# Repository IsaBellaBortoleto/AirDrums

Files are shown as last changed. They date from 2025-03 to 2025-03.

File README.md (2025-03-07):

## <h1 align="center">AIRDRUMS</h1>
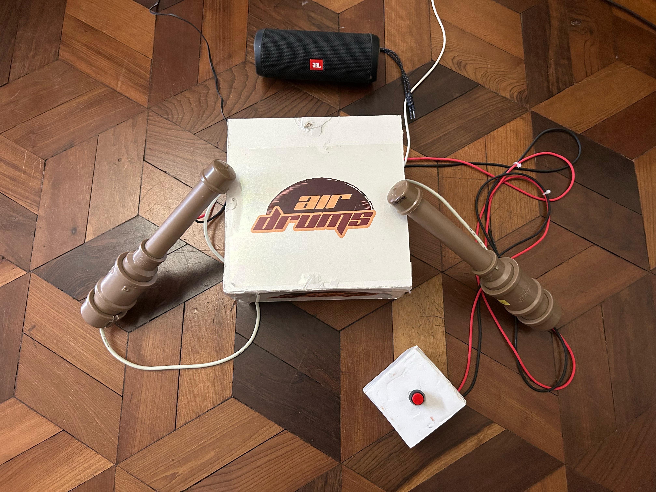
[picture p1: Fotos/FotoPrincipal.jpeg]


Como projeto da disciplina de Oficina de Integração I foi realizado o AirDrums, um sistema que utiliza sensores de movimento e tecnologia digital para simular a experiência de tocar bateria sem a necessidade de um instrumento físico volumoso.
A proposta do trabalho é oferecer uma alternativa compacta, permitindo a prática sem restrições de espaço ou ruído.

## Desenvolvedores  

- Bruna Medeiros Teixeira  
- Isabela Bella Bortoleto  
- Guilherme de Souza Carneiro Garcia  

## ⚙️ Componentes Utilizados  

- **ESP32 Dev Kit V1**: Microcontrolador principal do projeto, responsável por processar os dados dos sensores, interpretar os movimentos e gerenciar a reprodução dos sons da bateria virtual. Nesse contexto, dois ESP32 são usados para capturar os dados das baquetas e um ESP32 que processa os sinais e executa o áudio. A partir de agora, ele será chamado de ESP32 central.  

- **IMU MPU6050 (Inertial Measurement Unit - Unidade de Medição Inercial)**: Unidade de acelerômetro e giroscópio integrado às baquetas, detecta os movimentos do usuário, identificando a posição das batidas na bateria virtual.  

- **DAC UDA1334A (Digital-to-Analog Converter - Conversor Digital-para-Analógico)**: Converte os sinais digitais de áudio do ESP32 central em sinais analógicos, permitindo a reprodução dos sons da bateria através de alto-falantes ou fones de ouvido.  

- **MicroSD**: Armazena os arquivos de áudio das peças da bateria (tons, pratos e bumbo) e fornece os dados para reprodução conforme os comandos recebidos.  

- **Botão Push-Button**: Botão de ativação, aciona manualmente o som do bumbo, simulando o pedal tradicional da bateria.  

- **Fonte de Alimentação para protoboard 3,3/5 V**: Responsável por fornecer energia para todos os módulos eletrônicos do sistema.  

Além deles, foram utilizadas placas universais (PCBs) para a integração elétrica das baquetas e do ESP32 central, uma estrutura de madeira projetada para acomodar os componentes e garantir sua segurança, cabos Manga para comunicação e alimentação das baquetas virtuais e uma estrutura de tubos de PVC para proteger e realizar o acabamento das baquetas, um resistor de 10kΩ para limitar a corrente no circuito do botão e massa para madeira para aperfeiçoar o acabamento da estrutura externa. Também foram utilizados jumpers para conectar os diversos módulos do circuito.

## 🔨 Desenvolvimento  

Os tópicos do desenvolvimento seguirão o fluxo de informações enviadas pelos componentes da bateria: ao serem acionadas, as baquetas ou o bumbo enviam os dados para o ESP32 central, que então processa e reproduz o som correspondente.  

A **Figura 2** apresenta uma representação geral do projeto.  

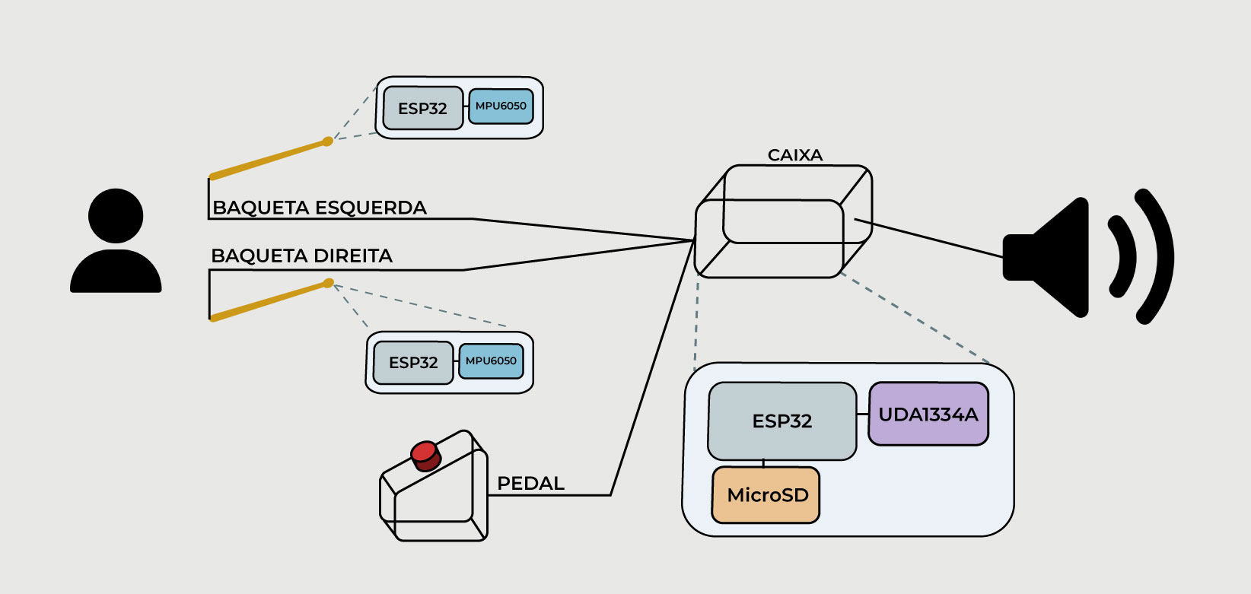
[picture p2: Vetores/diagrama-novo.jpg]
>  <br/>
> Figura 2: Diagrama funcional das AirDrums, Fonte: Autoria Própria.

### 🎯 Funcionamento das Baquetas  

O funcionamento das baquetas é baseado na integração de um **ESP32** e um **módulo MPU-6050** em cada baqueta, como mostra a **Figura 2**. Ao ligar o aparelho, o módulo realiza uma calibração inicial e começa a captar os giros de dois eixos principais:  

- O giro no eixo **Y** é usado para captar os movimentos de batida.  
- O giro no eixo **Z** é utilizado para determinar a região das partes da bateria.  

No código das baquetas, foi utilizada a biblioteca do módulo desenvolvida **Electronic Cats (Cats, 2025)**, que possibilita a ativação do **Digital Motion Processor (DMP)**.  

O **DMP** é um circuito integrado ao **MPU-6050**, que tem como objetivo refinar a carga do processamento das informações fornecidas pelo módulo, realizando cálculos complexos e aplicando filtros nos dados brutos captados pelo sensor. Esse processamento é realizado por um código proprietário, desenvolvido pela fabricante do módulo, a **InvenSense**, de código fechado.  

Como resultado, ele entrega informações mais elaboradas, na forma dos ângulos **Yaw** (Guinada, rotação no eixo Z), **Pitch** (Arfagem, rotação no eixo X) e **Roll** (Rolamento, rotação no eixo Y), como são chamados após a aplicação dos filtros internos, processados diretamente pelo DMP.  

Com isso, definimos zonas de ativação para cada parte da bateria através das baquetas, utilizando a posição relativa ao eixo **Z (Yaw)**. A **Figura 3** descreve os pontos de ativação de cada componente da bateria, assim como os ângulos de ativação.  

As zonas foram assim determinadas para respeitar as partes naturais da bateria, garantir precisão e fácil utilização do aparelho, sendo que as **faixas neutras** não correspondem a nenhum som e foram definidas para evitar conflito entre os pratos e tons.  

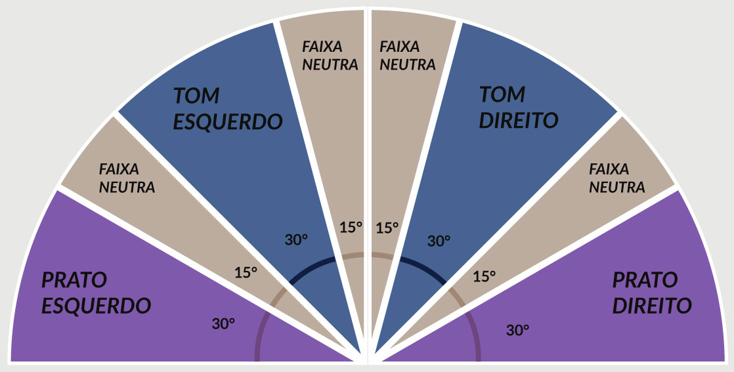
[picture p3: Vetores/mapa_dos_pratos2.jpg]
>  <br/>
> Figura 3: Ângulos de Ativação das Partes da Bateria, Fonte: Autoria Própria.<br />

Para o lançamento do som, utilizamos a posição relativa ao eixo **Y (Roll)**, é utilizado um ângulo de 10° para ativação, uma vez que corresponde ao movimento natural de tocar a bateria.  
O **ESP32** trabalha de forma sequencial para identificar a ativação da peça, o módulo envia essa informação para a parte central. Toda a comunicação dos módulos **MPU** é feita através do protocolo **I2C**, que manda os dados pós-processados para as **ESP32** da baqueta, então esses identificam a parte da bateria e enviam essa informação em formato de texto através da porta de comunicação **TX** utilizando o protocolo de comunicação **UART** (**Universal Asynchronous Receiver-Transmitter**), utilizado na troca de informações entre o microcontrolador da baqueta e o central, responsável por processar e reproduzir o som correto.  

Essa informação é transmitida por meio de um cabo **Manga** de três vias, que, além de transmitir os dados, também fornece alimentação de 5 V para todo o sistema.  

Por fim, as baquetas foram montadas em uma estrutura de **PVC**, projetada para se assemelhar ao instrumento original e proporcionar maior ergonomia durante o uso. A estrutura é composta por dois tubos de **PVC**, um com diâmetro de 40 mm e outro de 20 mm, conectados por luvas de redução por meio de encaixe por pressão. Para acabamento e proteção das extremidades, foram utilizadas tampas apropriadas para cada diâmetro. As baquetas possuem um comprimento de 28,5 cm no total.  

### 🔊 Implementação do som  
Após as baquetas detectarem a parte correspondente da bateria, essas informações são enviadas para o **ESP32** central, responsável pelo processamento dos dados e reprodução do som. Nele, temos três módulos integrados ao projeto:

- **Módulo Micro-SD**: O sistema utiliza um cartão microSD para armazenar os arquivos de áudio das diferentes peças do instrumento. O microprocessador central acessa esses arquivos, que estão em formato digital, através da biblioteca **SD.h**. Para otimizar a reprodução, os dados dos arquivos são lidos sequencialmente e armazenados temporariamente em um buffer na memória do **ESP32**, antes de serem processados e enviados para os alto-falantes.
  
- **Botão de Ativação do Bumbo**: O **ESP32** central controla a ativação do bumbo por meio de um botão (**push button**), a detecção do acionamento ocorre através da variação da diferença de potencial (**DDP**) no pino digital do **ESP32** ao qual o botão está conectado. Quando pressionado, o botão fecha o circuito, alterando o nível lógico do pino de entrada, permitindo que o **ESP32** identifique a ativação do comando. O botão está conectado eletricamente à placa de circuito impresso (**PCB**) central por meio de um fio soldado de 2,0 m de comprimento. Para facilitar o acionamento com o pé, o botão foi integrado a uma estrutura de madeira com uma tampa angulada, projetada para dar mais conforto e ergonomia durante o uso. A **Figura 6** demonstra o modelo 3D projetado para a caixa do bumbo, feito no **SolidWorks**.  

As dimensões do bumbo são:  
- Parte superior: quadrado de 8,0 cm x 8,0 cm;  
- Frente: retângulo de 7,1 cm x 8,1 cm;  
- Laterais trapezoidais: base inferior de 8 cm, base superior inclinada de 8,5 cm, altura variando entre 7,0 cm e 9,0 cm;  
- Parte traseira: retângulo de 10,3 cm x 8,1 cm;  
- Fundo: retângulo de 8,2 cm x 8,0 cm.  

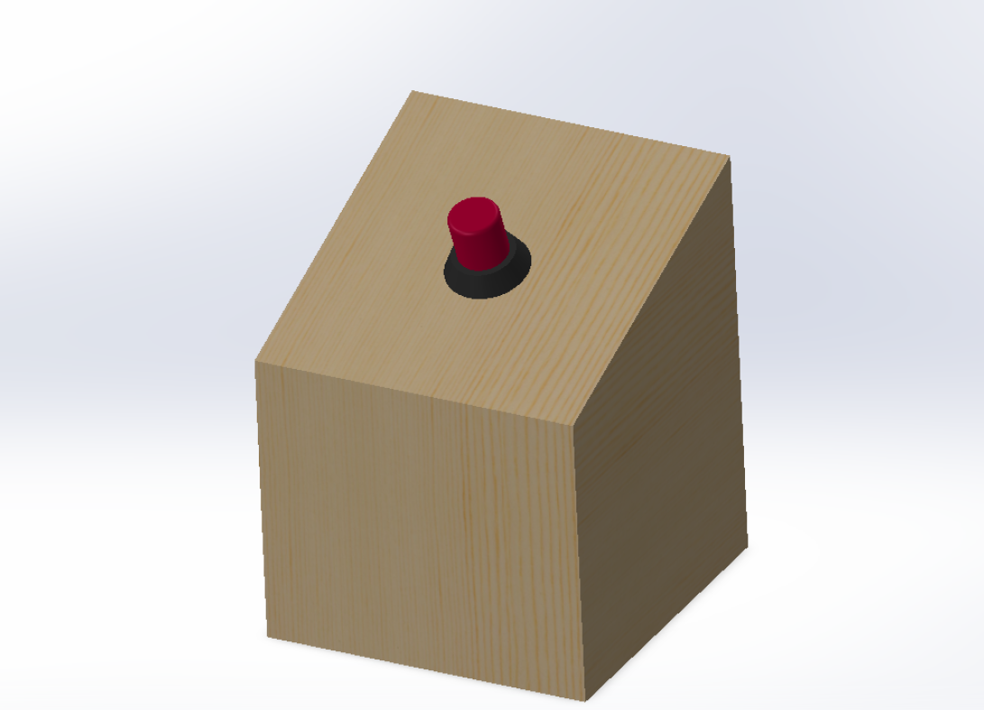
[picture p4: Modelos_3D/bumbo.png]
>  <br/>
> Figura 4. Modelo 3D da Estrutura do Bumbo. Fonte: Autoria Própria.

- **Módulo DAC UDA1334**: Após a abertura dos arquivos de áudio no módulo microSD e o acionamento de uma peça da bateria por meio das baquetas ou o toque no botão que integra o bumbo, inicia-se o processo de reprodução do som. O ESP32 utiliza a interface I2S, um protocolo otimizado para transmissão de áudio digital com baixa latência. A biblioteca I2S.h permite maior flexibilidade e ajustes na configuração do áudio com o DAC UDA1334. Para o projeto, escolhemos um padrão de áudio amplamente utilizado, com taxa de amostragem de 44,1 kHz e 16 bits. Além disso, foi utilizado o formato WAV, um formato de áudio não compactado que armazena os dados no padrão PCM (Pulse Code Modulation).

O UDA1334 recebe esses dados digitais enviados pelo ESP32 e os converte em sinais analógicos, que são representações contínuas das ondas sonoras. Diferente do áudio digital, que processa o som em valores discretos (bits), o sinal analógico corresponde às oscilações da pressão do ar, tornando o som audível para o ser humano. Como alto-falantes e fones de ouvido operam exclusivamente com sinais analógicos, eles convertem essas variações elétricas em ondas sonoras e reproduzem o áudio para esses dispositivos através de uma saída P2.

Por fim, todo esse sistema foi soldado em uma PCB central de 10 por 10 cm, junto com um módulo regulador de tensão de 5 V para protoboard e um cabo de alimentação de 9 V, responsável por fornecer energia ao sistema. Tudo isso foi colocado em uma estrutura quadrada de madeira, com dimensões de 20,2 x 20,2 x 14 cm.

O esquema elétrico, desenvolvido por meio do software EasyEDA, pode ser visualizado na Figura 5.

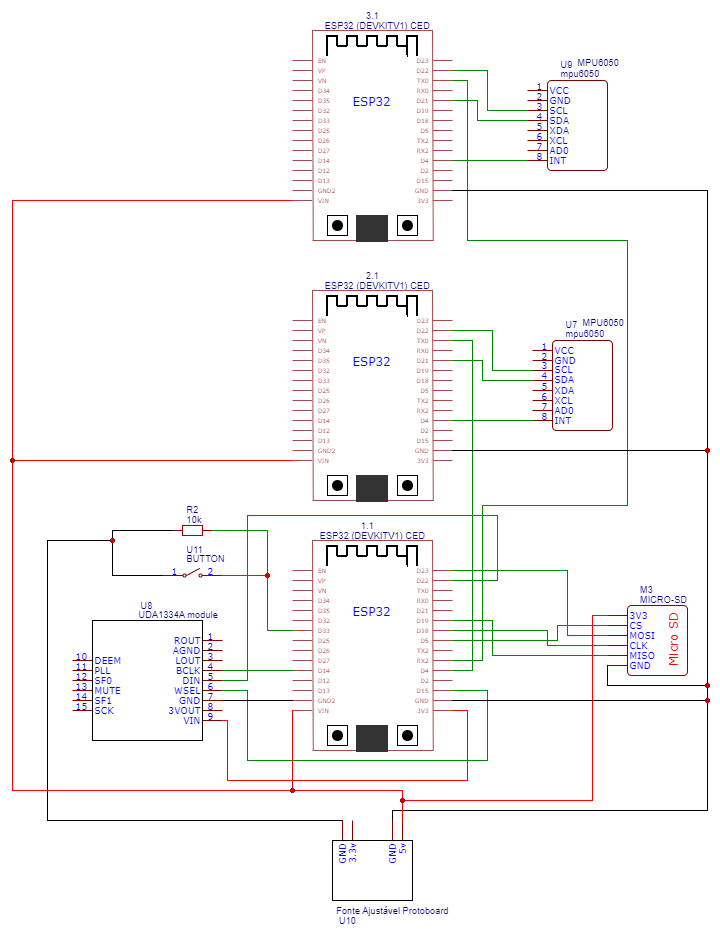
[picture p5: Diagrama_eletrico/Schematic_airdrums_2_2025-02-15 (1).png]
>  <br/>
> Figura 5. Diagrama do Circuito Elétrico. Fonte: Autoria Própria.

---

Para mais informações, leia o [artigo disponível no repositório.](https://github.com/IsaBellaBortoleto/AirDrums/blob/main/Artigo.pdf)

<p float="left">
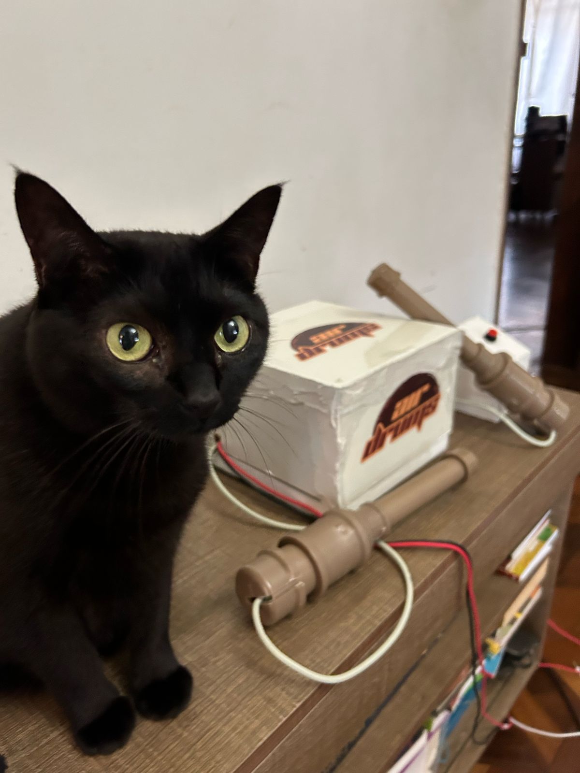
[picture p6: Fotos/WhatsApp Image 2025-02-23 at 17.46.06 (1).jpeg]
  
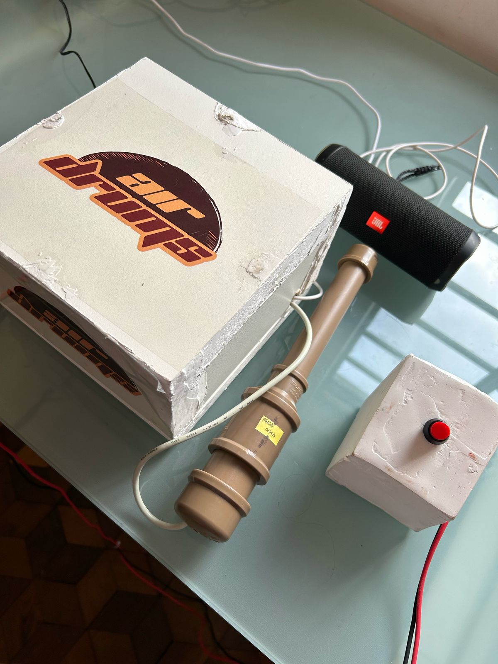
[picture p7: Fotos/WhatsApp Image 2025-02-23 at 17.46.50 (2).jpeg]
   
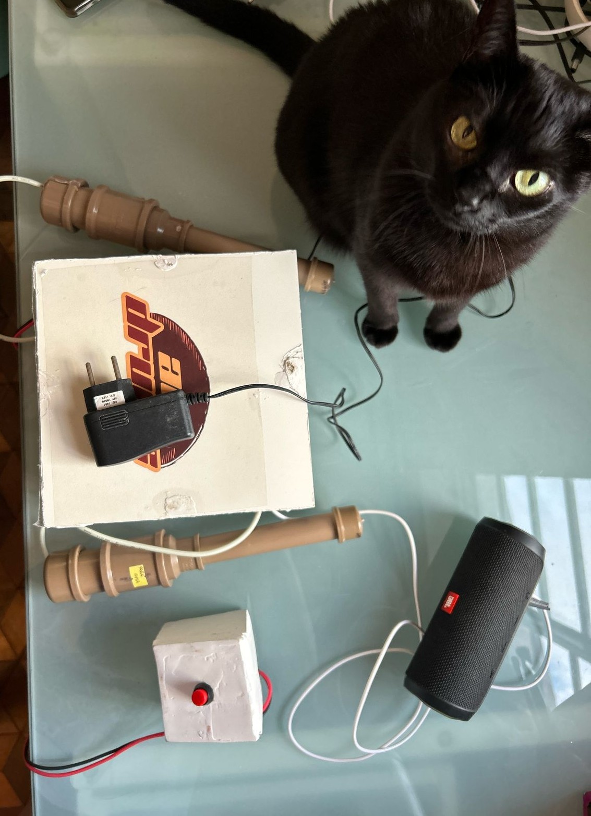
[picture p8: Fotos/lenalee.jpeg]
  
</p>

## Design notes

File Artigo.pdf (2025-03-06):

## Projeto AirDrums

Guilherme de S.C Garcia ∗ Bruna M Teixeira ∗∗ Isabela Bella Bortoleto ∗∗∗

∗ Faculdade de Engenharia da Computação, Universidade Tecnológica Federal do Paraná, PR, (e-mail: garciag@alunos.utfpr.edu.br).
∗∗ Faculdade de Engenharia da Computação, Universidade Tecnológica Federal do Paraná, PR, (e-mail: brunat@alunos.utfpr.edu.br)
∗∗∗ Faculdade de Engenharia da Computação, Universidade Tecnológica Federal do Paraná, PR, (e-mail: isabelabortoleto@alunos.utfpr.edu.br)

Abstract: The AirDrums project refers to the reproduction of an acoustic drum set through electronic components, aiming to be compact and quieter. The project uses MPU6050 inertial sensors and the ESP32 microcontroller to map the drum components and determine which sound will be played. The sound is stored on a microSD card and reproduced through a UDA1334 DAC module in a compatible speaker or headphone. The project demonstrates the ability to detect activation zones and sound reproduction; however, it is recognized that improvements in responsiveness and playability are still needed.
Resumo: O projeto AirDrums refere-se à reprodução de uma bateria acústica através de componentes eletrônicos, visando ser compacto e mais silencioso. O projeto usa sensores inerciais MPU6050 e o microcontrolador ESP32 para mapear as partes da bateria e determinar qual som será tocado. O som é armazenado em um cartão microSD para ser reproduzido por um módulo DAC UDA1334 em um alto-falante ou fone de ouvido compatível. O projeto demonstra capacidade de detectar as zonas de ativação e reprodução sonora, porém, é reconhecido que ainda precisa de melhorias na responsividade e tocabilidade.

Keywords: Musical drums; Digital musical instrument; Inertial sensors; Audio processing; Gesture interaction.
Palavras-chaves: Bateria musical; Instrumento musical digital; Sensores Inerciais; Processamento de áudio; Interação gestual.
1. INTRODU ÇAÕ

A bateria é um dos instrumentos mais versáteis e difundidos da música moderna, sendo essencial para a construção da identidade sonora de diversos estilos. Sem o kit de bateria, gêneros como rock, jazz e funk seriam irreconhecíveis. Ele forneceu a gramática rítmica para a cultura musical global do século XX. Sua evolução permitiu a criação de novas formas de expressão musical, consolidando-se como um elemento central em gêneros contemporâneos Brennan (2020).

No entanto, a música acompanha a humanidade desde os primórdios. Achados arqueológicos indicam que instrumentos musicais já eram utilizados há pelo menos 35.000 a 40.000 anos, conforme evidenciado pela descoberta de flautas feitas de ossos de pássaros e marfim na região da Suábia, na Alemanha Conard et al. (2009). Ao longo da história, os instrumentos evoluíram e se adaptaram às necessidades culturais e tecnológicas de cada época.

Atualmente, a prática da bateria enfrenta desafios crescentes devido a mudanças na estrutura urbana e nas condições de moradia. De acordo com um estudo da Fundação Instituto de Pesquisas Econômicas (Fipe) em parceria com a Associação Brasileira de Incorporadoras Imobiliárias

(ABRAINC), o tamanho médio das casas financiadas no Brasil passou de 58 m²

em 2018 para 66 m²
em 2021,
enquanto os 10% mais ricos financiam imóveis com 136 m² (FIPE e ABRAINC (2021)). Isso representa um desafio para a prática da bateria, uma vez que um instrumento desse porte requer um espaço considerável dentro do ambiente residencial e pode ser difícil de acomodar em moradias compactas, como as casas financiadas. Além disso, as restrições de poluição sonora em ambientes urbanos limitam seu uso, aumentando a necessidade de alternativas mais silenciosas.

Diante desses desafios, este artigo apresenta o projeto AirDrums, um sistema que utiliza sensores de movimento e tecnologia digital para simular a experiência de tocar bateria sem a necessidade de um instrumento físico volumoso. A proposta do projeto é oferecer uma alternativa compacta, permitindo a pratica sem restrições de espaço ou ruído.

2. TRABALHOS RELACIONADOS

No que diz respeito à pesquisa e desenvolvimento relacionados ao avanço da integração de soluções tecnológicas aplicadas à prática de instrumentos musicais, diversos kits de bateria virtuais têm sido desenvolvidos, como o Aerodrums Kit e o PocketDrum 2 Max da Aeroband. Muitos outros trabalhos nesta área buscam proporcionar melhores experiências na prática deste instrumento, servindo como inspiração para a realização desse projeto. Nesse contexto, apresentamos brevemente alguns trabalhos que desempenham um papel relevante no avanço da integração tecnológica com o ambiente musical:

2.1 AirSticks 2.0: Instrument Design for Expressive Gestural Interaction

Essa projeto feito por Trolland et al. (2022), foi publicado na conferência NIME (New Interfaces for Musical Expression), reconhecida como um dos principais eventos internacionais dedicados ao avanço de tecnologias musicais.

O trabalho apresenta o desenvolvimento do AirSticks 2.0, um instrumento musical projetado para interação gestual expressiva. Utilizando sensores de movimento, o AirSticks 2.0 permite aos músicos criar sons percussivos e melódicos em tempo real.

Os pesquisadores discutem os desafios enfrentados no desenvolvimento do AirSticks 2.0, incluindo a minimização de latência, a complexidade do mapeamento de gestos para sons e a necessidade de oferecer uma experiência mais intuitiva aos usuários.

2.2 Airstic Drum: A Drumstick for Integration of Real and Virtual Drums

Conduzido por Kanke et al. (2012), esse trabalho apresenta o desenvolvimento do Airstic Drum, um dispositivo projetado para integrar tambores reais e virtuais. O sistema utiliza sensores de aceleração e giroscópio incorporados em baquetas, permitindo que o Airstic Drum reconheça gestos e diferencie entre golpes em tambores reais e virtuais. O dispositivo é capaz de emitir sons digitais apenas quando os tambores virtuais são acionados, mantendo a naturalidade dos movimentos dos bateristas.

Os criadores destacam os desafios enfrentados no design, como a necessidade de precisão no reconhecimento dos movimentos e a minimização de atrasos na emissão dos sons digitais. Além disso, o trabalho detalha a implementação do protótipo e os resultados de experimentos de avaliação que confirmaram a eficácia do sistema na integração de tambores reais e virtuais.

2.3 A Comprehensive Review of Sensors and Instrumentation Methods in Devices for Musical Expression

Publicado na revista Sensors por Medeiros and Wanderley (2014), esse artigo explora diversos sensores e métodos de instrumentação utilizados no desenvolvimento de dispositivos musicais. Este trabalho abrange tecnologias como sensores de movimento, pressão e posição, discutindo suas aplicações no campo da musica.

O objetivo desse trabalho é a análise das possibilidades oferecidas pelos sensores na criação de interfaces musicais. Os autores destacam a importância da escolha adequada de sensores para garantir precisão e responsividade, aspectos importantes para dispositivos baseados em gestos. Além disso, o artigo aborda desafios técnicos relacionados à latência, integração de hardware e mapeamento de gestos, fornecendo dados importantes para outros pesquisadores a respeito desses sensores.

Ao incluir uma visão histórica e tecnológica dos sensores musicais, o artigo contribui para a compreensão dos fundamentos que sustentam projetos que buscam integrar tecnologias ao sensores de movimento.

3. METODOLOGIA

A seção de metodologia deste artigo descreve o processo de desenvolvimento do projeto AirDrums, detalhando a integração entre hardware e software para a criação de um instrumento musical virtual. Serão apresentados os materiais utilizados, o processo de construção e integração das partes.

3.1 Descrição do Kit de Bateria

Antes de qualquer desenvolvimento, é importante descrever o kit que será utilizado no projeto. A bateria é um instrumento extremamente versátil, com diversas formas de montagem adaptadas às preferências de cada artista. O modelo escolhido como referência foi o kit utilizado pelo baterista inglês Ringo Starr, integrante da banda The Beatles, entre os anos de 1963 e 1964, conforme ilustrado na Figura 1. Para simplificar o projeto, optou-se por usar apenas uma parte do kit, com os seguintes componentes: o bumbo (a peça onde está escrito o nome da banda), dois tons (os tambores localizados logo acima do bumbo), diferenciados como tom esquerdo e tom direito, e dois pratos, sendo um prato de condução (o prato maior à direita) e um prato de ataque (o prato menor à esquerda, utilizado para acentuações). Para facilitar a nomenclatura ao longo do texto, os pratos serão chamados apenas de prato esquerdo e prato direito.

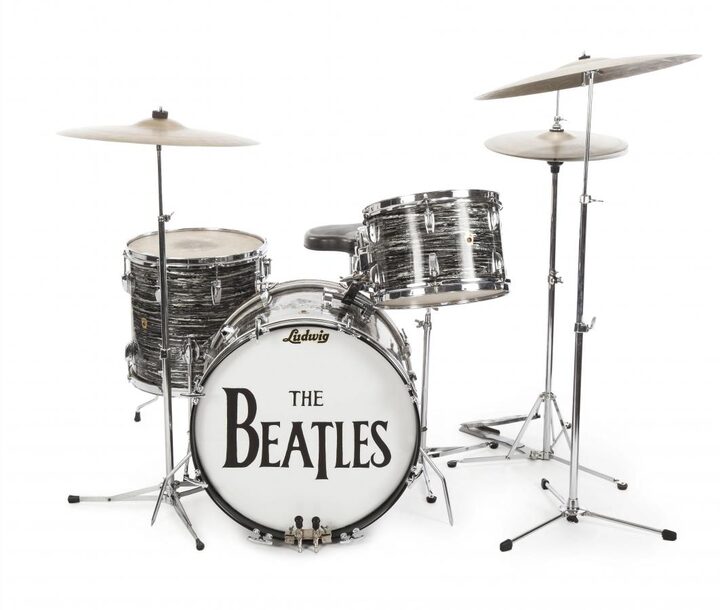
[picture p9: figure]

Figura 1. Modelo de bateria utilizado por Ringo Starr, entre 1963 e 1964. Fonte: Milliken (2015)

3.2 Componentes Utilizados

- ESP32 Dev Kit V1: Microcontrolador principal do projeto, responsável por processar os dados dos sensores, interpretar os movimentos e gerenciar a reprodução dos sons da bateria virtual. Nesse contexto, dois ESP32 são usados para capturar os dados das baquetas e um ESP32 que processa os sinais e executa o áudio, a partir de agora, ele será chamado de ESP32 central.

- IMU MPU6050 (Inertial Measurement Unit -Unidade de Medição Inercial): Unidade de acelerômetro e giroscópio integrado às baquetas, detecta os movimentos do usuário, identificando a posição das batidas na bateria virtual.
- DAC UDA1334A (Digital-to-Analog Converter -Conversor Digital-para-Analógico): Converte os sinais digitais de áudio do ESP32 central em sinais analógicos, permitindo a reprodução dos sons da bateria através de alto-falantes ou fones de ouvido.
- MicroSD: Armazena os arquivos de áudio das peças da bateria (tons, pratos e bumbo) e fornece os dados para reprodução conforme os comandos recebidos.
- Botão Push-Button: Botão de ativação, aciona manualmente o som do bumbo, simulando o pedal tradicional da bateria.
- Fonte de Alimentação para protoboard 3,3/5 V: Responsável por fornecer energia para todos os módulos eletrônicos do sistema.

Além deles, foram utilizadas placas universais (PCBs) para a integração elétrica das baquetas e do ESP32 central, uma estrutura de madeira projetada para acomodar os componentes e garantir sua segurança, cabos Manga para comunicação e alimentação das baquetas virtuais e uma estrutura de tubos de PVC para proteger e realizar o acabamento das baquetas, um resistor de 10kΩ para limitar a corrente no circuito do botão e massa para madeira para aperfeiçoar o acabamento da estrutura externa. Também foram utilizados jumpers para conectar os diversos módulos do circuito.

3.3 Softwares Utilizados

Nesta subseção, são apresentados os softwares empregados no desenvolvimento do projeto:

- Garage Band (Apple Inc.): Um software de produção musical usado para gravação, edição e mixagem de áudio. Inclui instrumentos virtuais, efeitos e loops. No projeto AirDrums, foi utilizado para gravar os sons das diferentes peças da bateria, como o bumbo, os tons (esquerdo e direito) e os pratos (direito e esquerdo), a fim de armazená-los no cartão microSD.
- Audacity (Audacity Team): Um software de edição de arquivos de áudio. No projeto, foi utilizado para processar os arquivos gerados pelo Garage Band, realizando ajustes e convertendo-os para o formato WAV, compatível com o ESP32.
- Arduino IDE (Arduino LLC): Um ambiente de desenvolvimento integrado projetado para facilitar a programação de microcontroladores da plataforma Arduino e compatíveis. No projeto AirDrums, foi utilizado para desenvolver e testar o código, além de enviá-lo ao ESP32. Além de possibilitar gerenciar a comunicação com os sensores e periféricos conectados.
- EasyEDA (EasyEDA LLC): Uma plataforma de design eletrônico que oferece ferramentas para criação de diagramas esquemáticos e layout de placas de circuito impresso (PCBs). No projeto, foi utilizado para criar o diagrama esquemático completo do circuito.
- SolidWorks (Dassault Systèmes SE): Um dos softwares de CAD (projeto e desenho assistido por computador). Ele permite criar modelos tridimensionais detalhados, realizar simulações e produzir desenhos técnicos para fabricação. No projeto AirDrums, foi usado para modelar as estruturas de suporte do sistema, permitindo visualizar e ajustar o design antes da produção.

3.4 Desenvolvimento

Os tópicos do desenvolvimento seguirão o fluxo de informações enviadas pelos componentes da bateria: ao serem acionadas, as baquetas ou o bumbo enviam os dados para o ESP32 central, que então processa e reproduz o som correspondente. A Figura 2 apresenta uma representação geral do projeto.

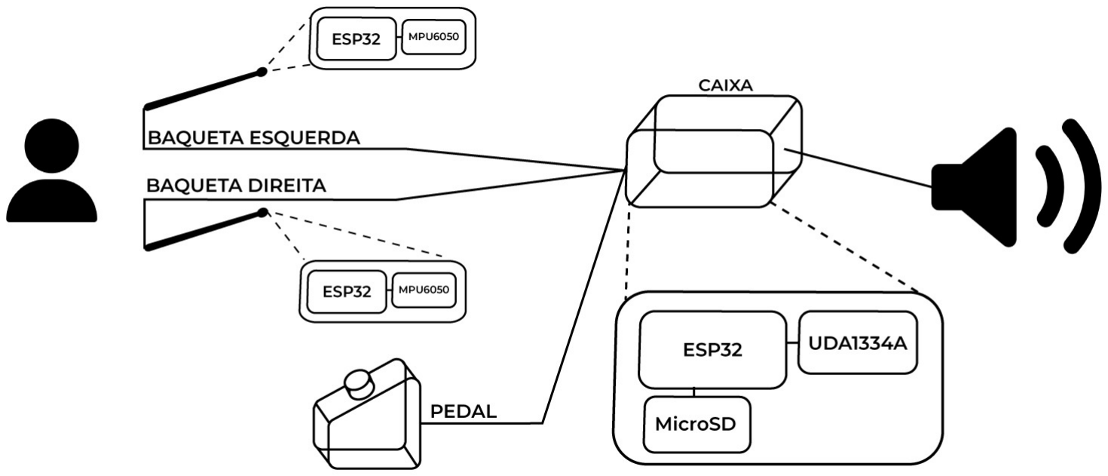
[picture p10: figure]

Figura 2. Diagrama funcional das AirDrums, Fonte: Autoria Própria

O funcionamento das baquetas é baseado na integração de um ESP32 e um módulo MPU-6050 em cada baqueta como mostra a Figura 2. Ao ligar o aparelho, o módulo realiza uma calibração inicial e começa a captar os giros de dois eixos principais: o giro no eixo Y é usado para captar os movimentos de batida, e o giro no eixo Z é utilizado para determinar a região das partes da bateria. A Figura 3 representa a visualização dos eixos do modulo.

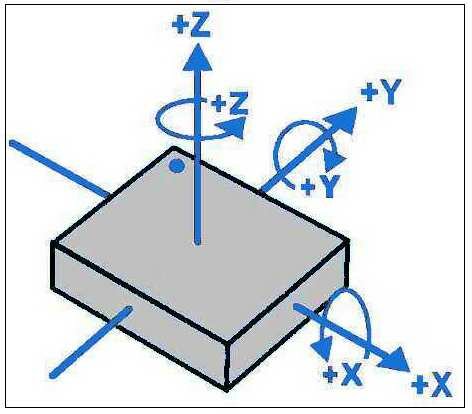
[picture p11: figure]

Figura 3. Representação dos Eixos do MPU-6050

No código das baquetas, foi utilizada a biblioteca do módulo desenvolvida Electronic Cats (Cats (2025)), que possibilita a ativação do Digital Motion Processor (DMP). O DMP é um circuito integrado ao MPU-6050 que tem como objetivo refinar a carga do processamento das informações fornecidas pelo módulo, realizando cálculos complexos e aplicando filtros nos dados brutos captados pelo sensor. Esse processamento é realizado por um código proprietário, desenvolvido pela fabricante do módulo, a InvenSense,de código fechado. Como resultado, ele entrega informações mais elaboradas, na forma dos ângulos Yaw (Guinada, rotação no eixo Z), Pitch (Arfagem, rotação no eixo X) e Roll (Rolamento, rotação no eixo Y),como são chamados após a aplicação dos filtros internos, processados diretamente pelo DMP.

Com isso, definimos zonas de ativação para cada parte da bateria através das baquetas, utilizando a posição relativa ao eixo Z (Yaw).A Figura 4 descreve os pontos de ativação de cada componente da bateria, assim como os ângulos de ativação. As zonas foram assim determinadas para respeitar as partes naturais da bateria, garantir precisão e fácil utilização do aparelho, sendo que as faixas neutras não correspondem a nenhum som e foram definidas para evitar conflito entre os pratos e tons.

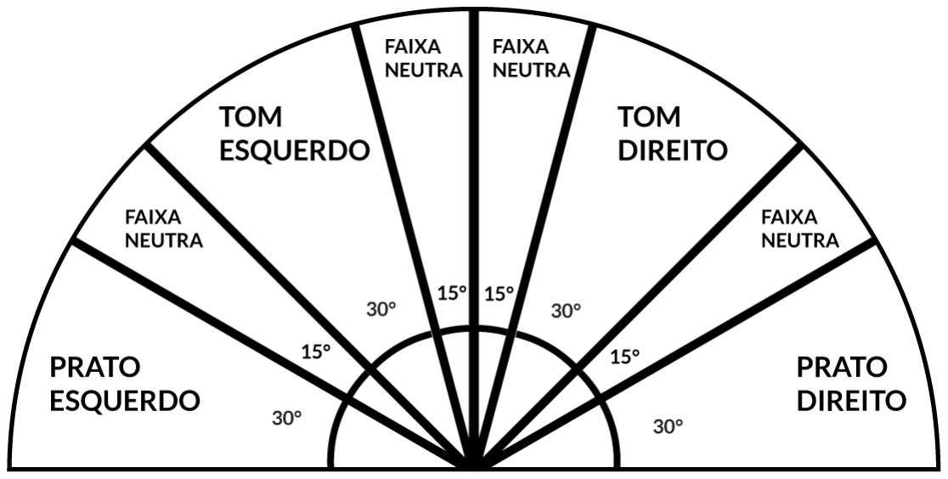
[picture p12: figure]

Figura 4. Angulos de Ativação das Partes da Bateria Fonte: ˆ Autoria Própria

Para o lançamento do som, utilizamos a posição relativa ao eixo Y (Roll), é utilizado um ângulo de 10° para ativação, uma vez que corresponde ao movimento natural de tocar a bateria.

O ESP32 trabalha de forma sequencial para identificar a ativação da peça, o módulo envia essa informação para a parte central. Toda a comunicação dos módulos MPU é feitas através do protocolo I2C, que manda os dados pós-processados para as ESP32 da baqueta, então esses identificam a parte da bateria e enviam essa informação em formato de texto através da porta de comunicação TX, conforme mostrado na Figura 7, utilizando o protocolo de comunicação UART (Universal Asynchronous Receiver-Transmitter ), utilizado na troca de informações entre o microcontrolador da baqueta e o central, responsável por processar e reproduzir o som correto. Essa informação é transmitida por meio de um cabo Manga de três vias, que, além de transmitir os dados, também fornece alimentação de 5 V para todo o sistema.

Por fim, as baquetas foram montadas em uma estrutura de PVC, projetada para se assemelhar ao instrumento original e proporcionar maior ergonomia durante o uso. A estrutura é composta por dois tubos de PVC, um com diâmetro de 40 mm e outro de 20 mm, conectados por luvas de redução por meio de encaixe por pressão. Para acabamento e proteção das extremidades, foram utilizadas tampas apropriadas para cada diâmetro. As baquetas possuem um comprimento de 28,5 cm no total. O resultado pode ser observado na Figura 5.

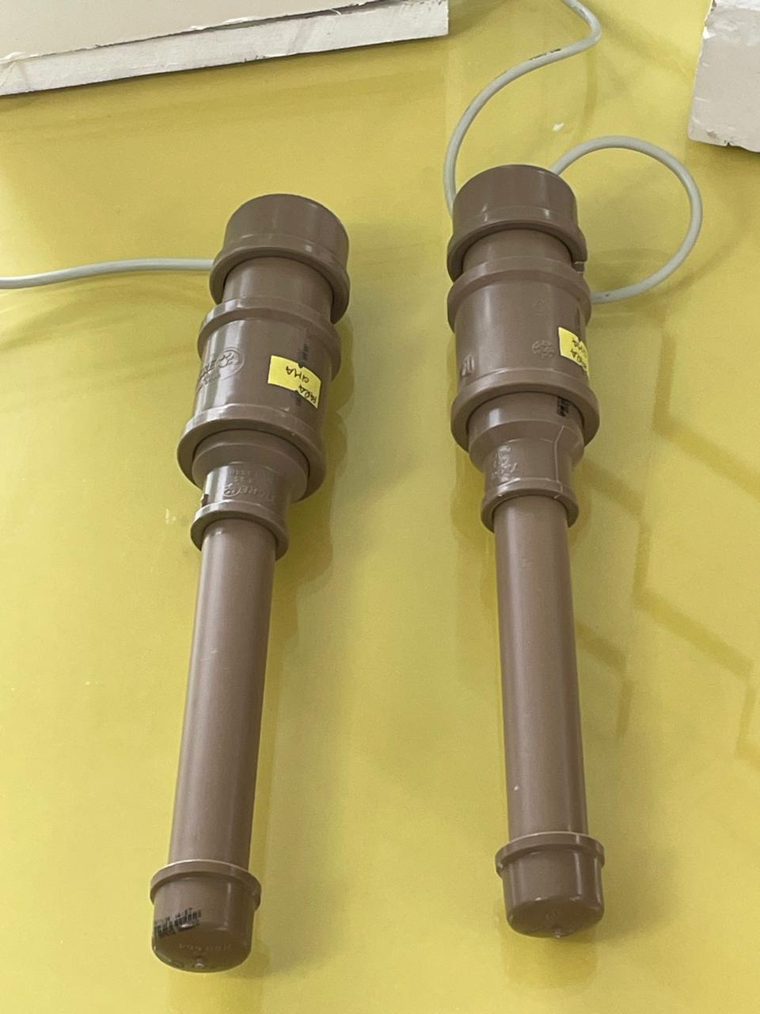
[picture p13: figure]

Figura 5. Diagrama do Circuito Elétrico Fonte: Autoria própria

Implementação do som Após as baquetas detectarem a parte correspondente da bateria, essas informações são enviadas para o ESP32 central, responsável pelo processamento dos dados e reprodução do som. Nele, temos três módulos integrados ao projeto:

- Módulo Micro-SD: O sistema utiliza um cartão microSD para armazenar os arquivos de áudio das diferentes peças do instrumento. O microprocessador central acessa esses arquivos, que estão em formato digital, através da biblioteca SD.h. Para otimizar a reprodução, os dados dos arquivos são lidos sequencialmente e armazenados temporariamente em um buffer na memória do ESP32, antes de serem processados e enviados para os alto-falantes.
- Botão de Ativação do Bumbo: O ESP32 central controla a ativação do bumbo por meio de um botão ( push bottom ), a detecção do acionamento ocorre através da variação da diferença de potencial (DDP) no pino digital do ESP32 ao qual o botão está conectado. Quando pressionado, o botão fecha o circuito, alterando o nível lógico do pino de entrada, permitindo que o ESP32 identifique a ativação do comando.
O botão está conectado eletricamente à placa de circuito impresso (PCB) central por meio de um fio soldado de 2,0 m de comprimento. Para facilitar o acionamento com o pé, o botão foi integrado a uma estrutura de madeira com uma tampa angulada, projetada para dar mais conforto e ergonomia durante o uso. A Figura 6 demonstra o modelo 3D projetado para caixa do bumbo, feito no SolidWorks.
As dimensões do bumbo são:
- Parte superior: quadrado de 8,0 cm x 8,0 cm;
- Frente: retângulo de 7,1 cm x 8,1 cm;
- Laterais trapezoidais: base inferior de 8 cm, base superior inclinada de 8,5 cm, altura variando entre 7,0 cm e 9,0 cm;
- Parte traseira: retângulo de 10,3 cm x 8,1 cm;

- Fundo: retângulo de 8,2 cm x 8,0 cm.

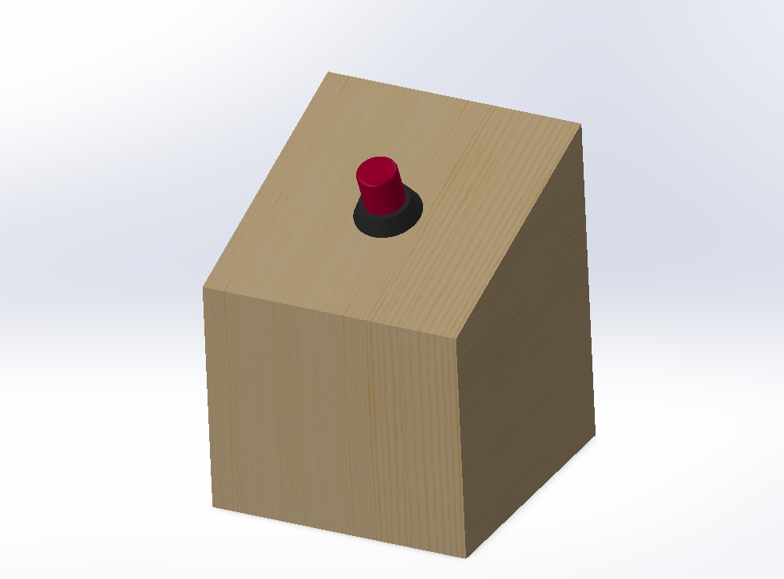
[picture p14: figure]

Figura 6. Modelo 3D da Estrutura do Bumbo. Fonte: Autoria própria

- Módulo DAC UDA1334: Após a abertura dos arquivos de áudio no módulo microSD e o acionamento de uma peça da bateria por meio das baquetas ou o toque no botão que integra o bumbo, inicia-se o processo de reprodução do som. O ESP32 utiliza a interface I2S, um protocolo otimizado para transmissão de áudio digital com baixa latência. A biblioteca I2S.h permite maior flexibilidade e ajustes na configuração do áudio com o DAC UDA1334. Para o projeto, escolhemos um padrão de áudio amplamente utilizado, com taxa de amostragem de 44,1 kHz e 16 bits. Além disso, foi utilizado o formato WAV, um formato de áudio não compactado que armazena os dados no padrão PCM (Pulse Code Modulation).
O UDA1334 recebe esses dados digitais enviados pelo ESP32 e os converte em sinais analógicos, que são representações contínuas das ondas sonoras. Diferente do áudio digital, que processa o som em valores discretos (bits), o sinal analógico corresponde às oscilações da pressão do ar, tornando o som audível para o ser humano. Como alto-falantes e fones de ouvido operam exclusivamente com sinais analógicos, eles convertem essas variações elétricas em ondas sonoras e reproduzem o áudio para esses dispositivos através de uma saída P2.

Por fim, todo esse sistema foi soldado em uma PCB central de 10 por 10 cm, junto com um módulo regulador de tensão de 5 V para protoboard e um cabo de alimentação de 9 V, responsável por fornecer energia ao sistema. Tudo isso foi colocado em uma estrutura quadrada de madeira, com dimensões de 20,2 x 20,2 x 14 cm.

O esquema elétrico, desenvolvido por meio do software EasyEDA, pode ser visualizado na Figura 7. Da mesma forma, a Figura 8 apresenta toda a montagem do projeto, incluindo as baquetas integradas à caixa central, o bumbo e sua estrutura de suporte.

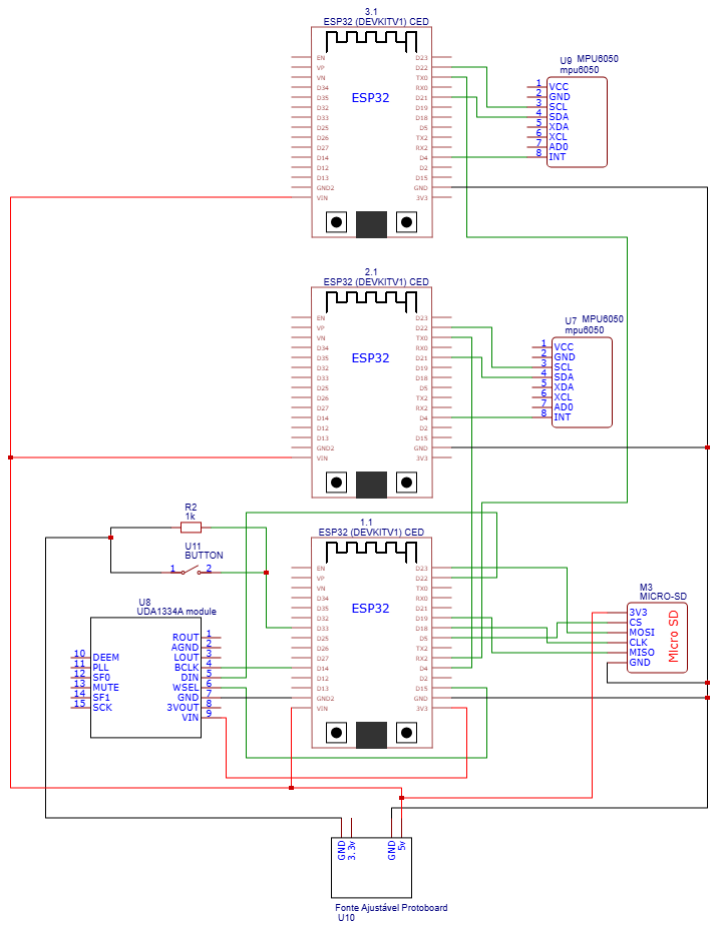
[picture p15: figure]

Figura 7. Diagrama do Circuito Elétrico Fonte: Autoria própria

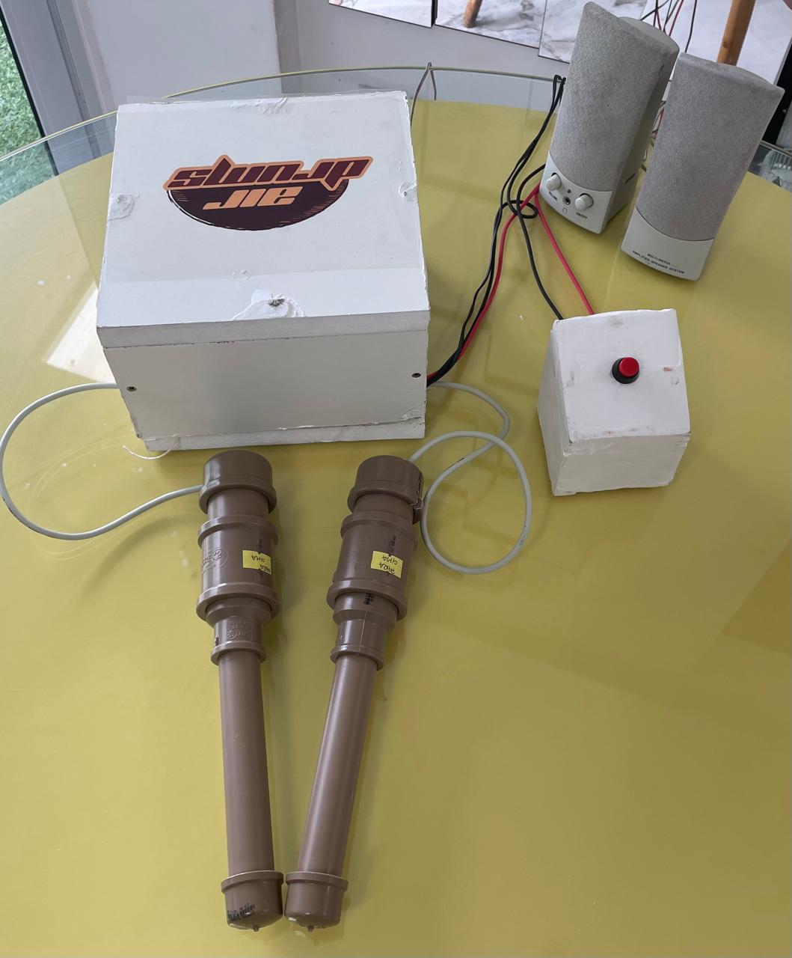
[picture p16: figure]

Figura 8. Montagem final das Aidrums Fonte: Autoria própria

4. RESULTADOS

4.1 Sobre as baquetas

Com base nos dados de posição (Yaw, Pitch e Roll) fornecidos pelo DMP do MPU6050, foi possível definir uma zona de ativação para cada parte da bateria, como mostrado na Figura 4. O uso do DMP reduziu o descalibramento do giroscópio, proporcionando uma estimativa mais estável das orientações. No entanto, algumas limitações foram observadas em situações de movimento rápido.

Os autores suspeitam que esses erros estejam relacionados a restrições físicas e mecânicas do módulo, especialmente devido à ausência de um magnetômetro, que normalmente é utilizado como referencial global para correção da orientação. Dessa forma, o MPU6050 baseia-se apenas nos dados do acelerômetro e do giroscópio para estimar os ângulos, o que pode contribuir para a ocorrência de uma deriva na referência ao longo do tempo.O reinicio do sistema se faz necessário após o acumulo progressivo da deriva . Esse comportamento é observado em diferentes projetos publicados na literatura Boiko et al. (2024); Wu and Pei (2017); Ruiz-García et al. (2021).

4.2 Sobre o Som

Em relação à qualidade sonora, os resultados foram satisfatórios. O volume de cada peça do kit foi ajustado para condições confortáveis nos testes realizados pelos integrantes do grupo e foi possível perceber o som correspondente a cada parte da bateria.

No entanto, conforme descrito no manual do módulo (Semiconductors (2012)), o módulo fornece um sinal de nível de linha (Line-Out), com baixa potência e corrente de saída. Dessa forma, ele foi projetado para operar com dispositivos compatíveis com esse tipo de sinal, como fones de ouvido de alta impedância e caixas de som amplificadas que possuem entrada auxiliar.

Em relação à rapidez e responsividade, o BPM representa a velocidade de repetição de um elemento rítmico, um parâmetro essencial para definir o andamento de uma composição musical.

O som de mais rápida reprodução no instrumento desenvolvido foi o bumbo da bateria. Uma sequência rápida de batidas ocorre a cada 0,7 segundos. O BPM correspondente pode ser calculado utilizando a seguinte equação:

BPM =

60
T

(1)

onde:

- BPM representa o número de batidas por minuto;
- T é o intervalo entre as batidas, expresso em segundos.

Substituindo T = 0, 7s, temos:

BPM =

60
0, 7
≈ 86 | (2)

Portanto, a frequência de batidas do bumbo nessa configuração corresponde aproximadamente a 86 BPM.

O som com maior tempo de ativação foi o do prato esquerdo, que leva 1,7 s para ser reproduzido repetidamente. Aplicando a equação 1:

BPM =

60
1, 7
≈ 36 | (3)

Então, para o prato, esse valor fica em aproximadamente 36 BPM.

Esse comportamento está diretamente ligado à forma como o ESP32 processa os comandos de ativação dos sons. Como o sistema opera de maneira sequencial, ou seja, o código não suporta a reprodução simultânea de múltiplos sons, quando detectado o comando, cada áudio precisa ser completamente reproduzido antes que um novo comando seja processado e, por isso, o índice BPM é baixo. Além disso, há um intervalo mínimo entre a detecção do movimento e a reprodução do som, o que influencia diretamente a taxa de resposta do instrumento e leva a uma pequena diminuição do BPM calculado.

A comunicação I2S utiliza um buffer, no qual os arquivos carregados do cartão microSD são enviados para reprodu-ção de forma sequencial e sem interrupções. Isso significa que, ao executar um som, o ESP32 continua lendo os comandos das baquetas, mas só processa um novo som depois que a reprodução atual for concluída. O diagrama da Figura 9 ajuda a entender o funcionamento do sistema e em qual parte do fluxo ocorre a reprodução do áudio.

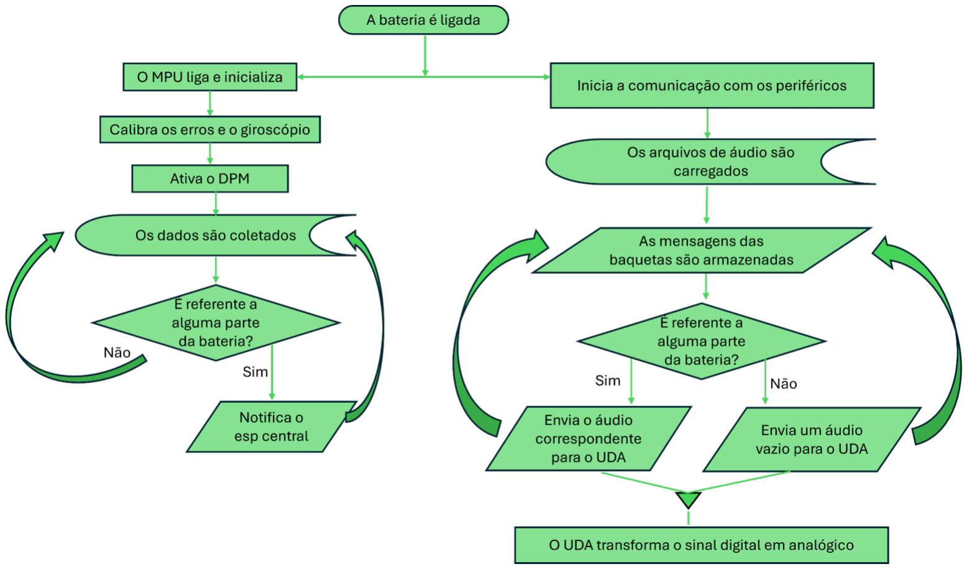
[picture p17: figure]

Figura 9. Fluxograma do Código da Bateria. Fonte: Autoria própria

4.3 Preço Total

Todos os matérias utilizados foram tabelados, junto com a quantidade e o custo parcial, no final é apresentado o total na Tabela 1.

5. CONCLUSAÕ

O sensor MPU-6050 se mostrou capaz de determinar as zonas de ativação da bateria com o auxílio da integração do DMP, reduzindo os efeitos da deriva progressiva. No entanto, fica notável que a ausência de um magnetômetro compromete a tocabilidade, já que o acúmulo dessa deriva afeta a precisão do reconhecimento das zonas ao longo do tempo. Sensores equipados com magnetômetro, como o ICM-20948 da InvenSense, poderiam fornecer um referencial absoluto, melhorando a calibração e a estabilidade do sistema.

Tabela 1. Custos das Peças.

Item (Quantidade) | Custo Parcial (R$)
Placa Universal (1x) | 36,17
ESP32 (3x) | 120,00
Acelerômetro e Giroscópio MPU-6050 (2x) | 40,00
Fonte de alimentação (1x) | 15,00
Módulo Micro SD (1x) | 12,00
Fios (1x) | 4,17
Push button (1x) | 2,50
Jumper fêmea-fêmea (1x) | 9,90
Pinos (1x) | 9,51
Decodificador de Audio I2S UDA1334A (1x) | 100,00 ´
Massa para madeira (1x) | 11,99
Lixa (1x) | 0,60
Canos (1x) | 72,16
Diversos (1x) | 20,00
Total | 454,00

Sobre a qualidade do som, o módulo UDA1334A conseguiu reproduzir os sons da bateria de forma eficiente, desde que usado com alto-falantes compatíveis com suas especificações. No entanto, a falta de um módulo amplificador de sinal limitou a compatibilidade com sistemas de som mais potentes e auto-falantes passivos. Nesse sentido, a sua inclusão poderia expandir a variedade de alto-falantes que compatíveis com o projeto.

A responsividade também apresentou limitações. Segundo o estudo de Gugnani (2024), músicas contemporâneas possuem BPMs que variam entre 60 e 204. O bumbo aproximou-se a 86 BPM e o prato esquerdo limitou-se a 36 BPM. Esse desempenho está abaixo do padrão da maioria das músicas atuais, o que restringe um pouco o uso em sistema em contextos musicais mais rápidos. Para melhorar isso, futuras versões poderiam otimizar a utilização do ESP32, explorando o uso dos seus dois núcleos para distribuir as tarefas de detecção de movimento e processamento de áudio de forma mais eficiente. Além disso, aprimorar o algoritmo para permitir a execução simultânea dessas operações poderia reduzir a latência e aumentar a resposta do sistema.

Por outro lado, nas questões espaciais, o projeto se mostrou compacto e ocupa um volume de apenas 0,006 m³ aproximadamente, que é muito inferior ao volume de baterias convencionais, normalmente compostas por dois tons, um surdo, uma caixa e um bumbo que ocupam entre 0,09 m³ a 0,12 m³
, o volume foi calculado com base em dados retirados do site da famosa marca de baterias e acessórios Ludwing Drums (n.d.).

Diante disso, o projeto mostrou potencial como um protótipo funcional de bateria acústica eletrônica baseada em sensores inerciais.

6. TRABALHOS FUTUROS

Entre as possibilidades para versões futuras, destaca-se a integração de sensores mais precisos nas baquetas, o uso de um microcontrolador mais robusto pode ser implementado, capaz de processar áudio de forma mais eficiente e trazer opções de efeitos espaciais e bibliotecas de processamento avançada de áudio, além do desenvolvimento de novos algoritmos e métodos para otimização do sistema. O projeto AirDrums ainda apresenta potencial para melhorias e otimizações em versões futuras, tornando-o cada vez mais preciso, responsivo e próximo da experiência de um instrumento musical real.

REFERENCIAS ˆ

Boiko, J., Svachii, O., and Ka laczyński, T. (2024). Control of unmanned aerial vehicle modules based on inertial measurement system and mems sensor. In 22nd International Conference Diagnostics of Machines and Vehicles, volume 391, 01005. doi:10.1051/matecconf/ 202439101005.
Brennan, M. (2020). Kick it: A social history of the drum kit. Oxford University Press. doi:10.1093/oso/ 9780190683870.001.0001.
Cats, E. (2025). Mpu6050 library. GitHub repository. URL https://github.com/ElectronicCats/mpu6050. Acessado em: fevereiro de 2025.
Conard, N.J., Malina, M., and Munzel, S.C. (2009). ¨ New flutes document the earliest musical tradition in southwestern germany. Nature, 460(7256), 737–740. doi: 10.1038/nature08169.
Drums, L. (n.d.). Element evolution. URL https://www.ludwig-drums.com/en-us/ludwig/products/drumkits/element-evolution. Acessado em: fevereiro de 2025.
FIPE e ABRAINC (2021). Indicadores de affordability
– 4t2021. | Technical report, Associação Brasileira
de Incorporadoras Imobiliárias, São Paulo. | URL
https://www.abrainc.org.br/uploads/2022/05/IndicadoresAffordability_4T2021.pdf. Acessado em: fevereiro de 2025.
Gugnani, V. (2024). Evolution of popular music: Analyzing two decades of shifts in the billboard top 10 (2003–23). SSRG International Journal of Humanities and Social Science, 11(6), 1–7. doi:10.14445/23942703/ IJHSS-V11I6P101.
Kanke, H., Takegawa, Y., Terada, T., and Tsukamoto, M. (2012). Airstic drum: A drumstick for integration of real and virtual drums. In Lecture Notes in Computer Science, volume 7624, 57–69. Springer. doi:10.1007/ 978-3-642-34292-9 5.
Medeiros, C.B. and Wanderley, M.M. (2014). A comprehensive review of sensors and instrumentation methods in devices for musical expression. Sensors, 14(8), 13556–13591. doi:10.3390/s140813556.
Milliken, | M. | (2015). | Ringo | starr | drum | kit
fetches | $2.2 | million | at | auction. | URL
https://www.reuters.com/article/lifestyle/ringo-starr-drum-kit-fetches-22-million-at-auction-idUSKBN0TP0NA. Ruiz-García, I., Navarro-Marchal, I., Ocaña-Wilhelmi, J.,
Palma, A.J., Gómez-López, P.J., and Carvajal, M.A.
(2021). Development and evaluation of a low-drift inertial sensor-based system for analysis of alpine skiing performance. Sensors, 21(7), 2480. doi:10.3390/s21072480. Semiconductors, N. (2012). Uda1334ats: Low-power audio dac with pll. Datasheet. URL https://www.nxp.com/docs/en/data-sheet/UDA1334ATS.pdf. Acessado em: fevereiro de 2025.
Trolland, S., Ilsar, A., Frame, C., McCormack, J., and Wilson, E. (2022). Airsticks 2.0: Instrument design for expressive gestural interaction. In NIME 2022. doi: 10.21428/92fbeb44.c400bdc2.

Wu, Y. and Pei, L. (2017). Gyroscope calibration via magnetometer. IEEE Sensors Journal, 17(16), 5301– 5308. doi:10.1109/JSEN.2017.2724538.

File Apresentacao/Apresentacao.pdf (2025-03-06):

# AIR

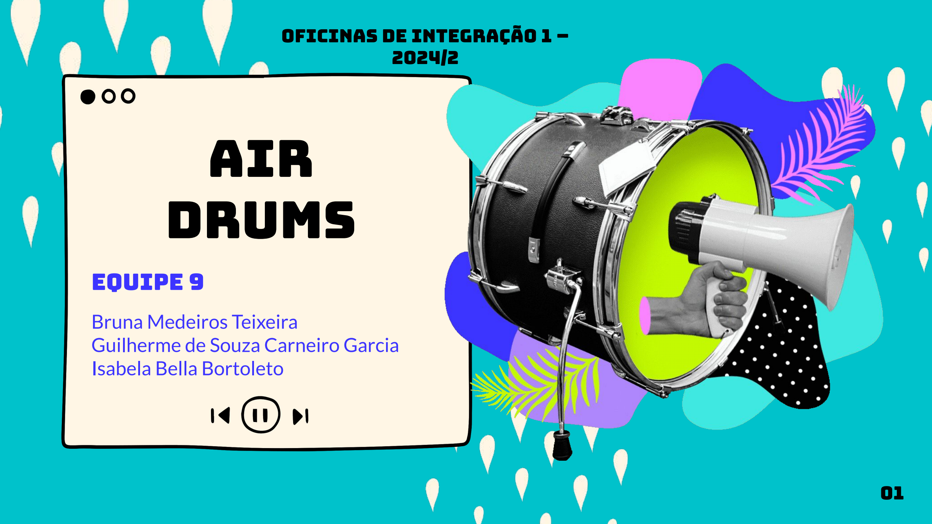
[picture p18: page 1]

# DRUMS

## Equipe 9

Bruna Medeiros Teixeira
Guilherme de Souza Carneiro Garcia Isabela Bella Bortoleto

Oficinas de integração 1 – 2024/2

# introdução

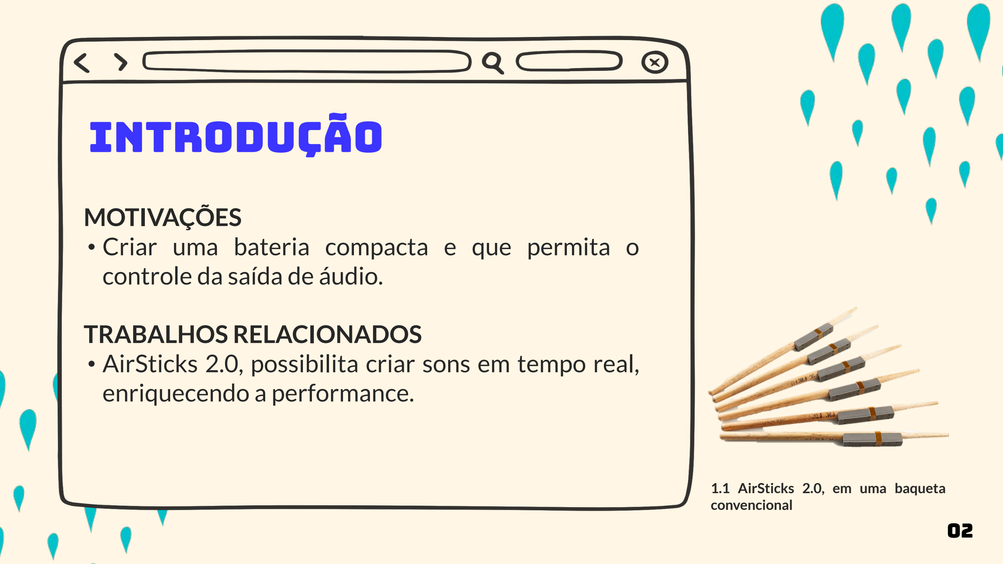
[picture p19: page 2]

MOTIVAÇÕES
- Criar uma bateria compacta e que permita o controle da saída de áudio.

TRABALHOS RELACIONADOS
- AirSticks 2.0, possibilita criar sons em tempo real, enriquecendo a performance.

### 1.1 AirSticks 2.0, em uma baqueta

convencional

# Diagrama do projeto

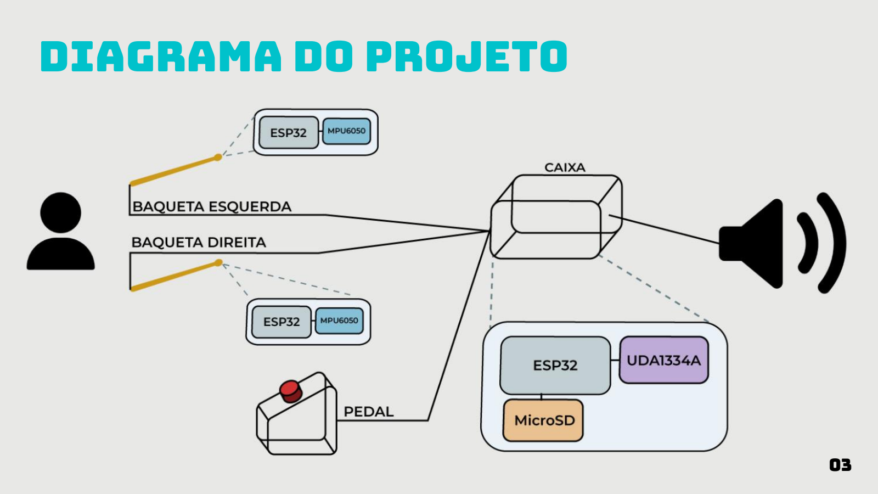
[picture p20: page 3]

# DIAGRAMA DAS ZONAS RECONHECIDAS PELA BATERIA

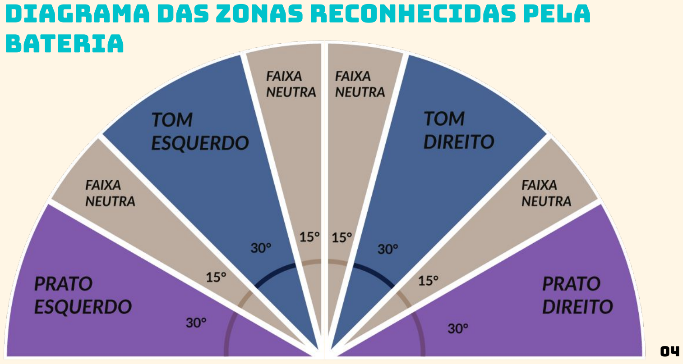
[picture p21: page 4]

4

# Principais MATERIAIS

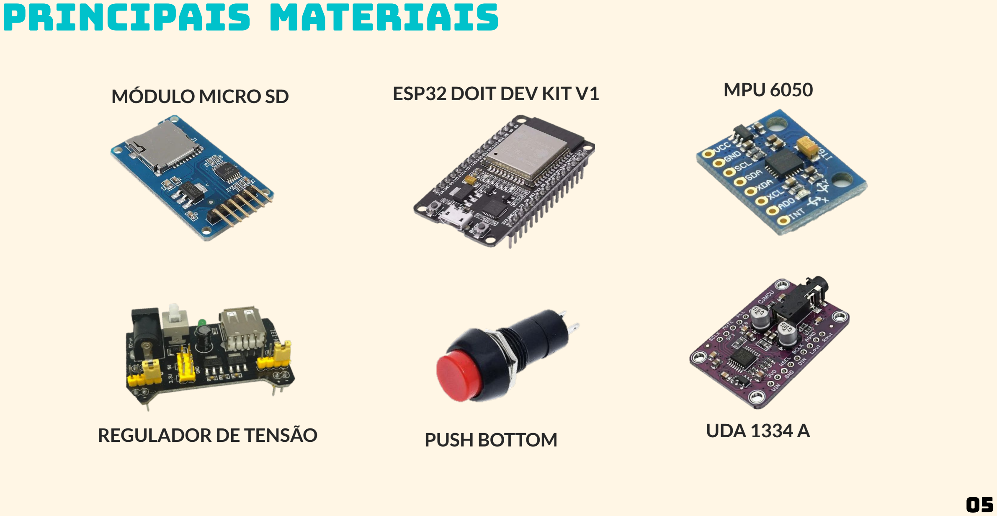
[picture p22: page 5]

MÓDULO MICRO SD | MPU 6050

REGULADOR DE TENSÃO

ESP32 DOIT DEV KIT V1

PUSH BOTTOM

UDA 1334 A

# circuito principal

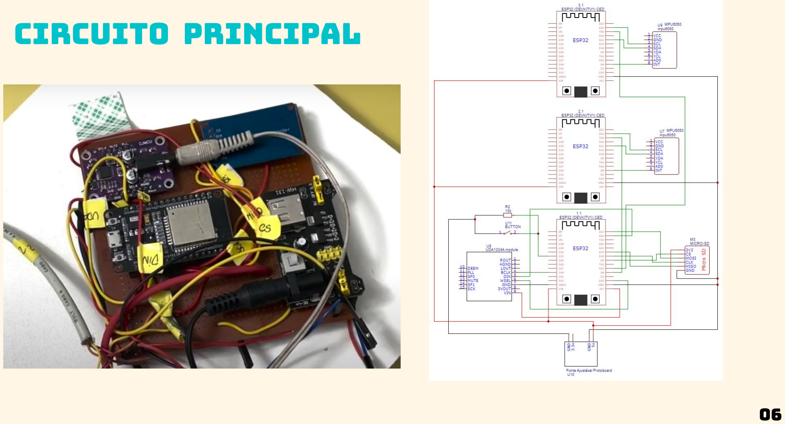
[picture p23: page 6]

# FUNCIONAMENTO DA BATERIA

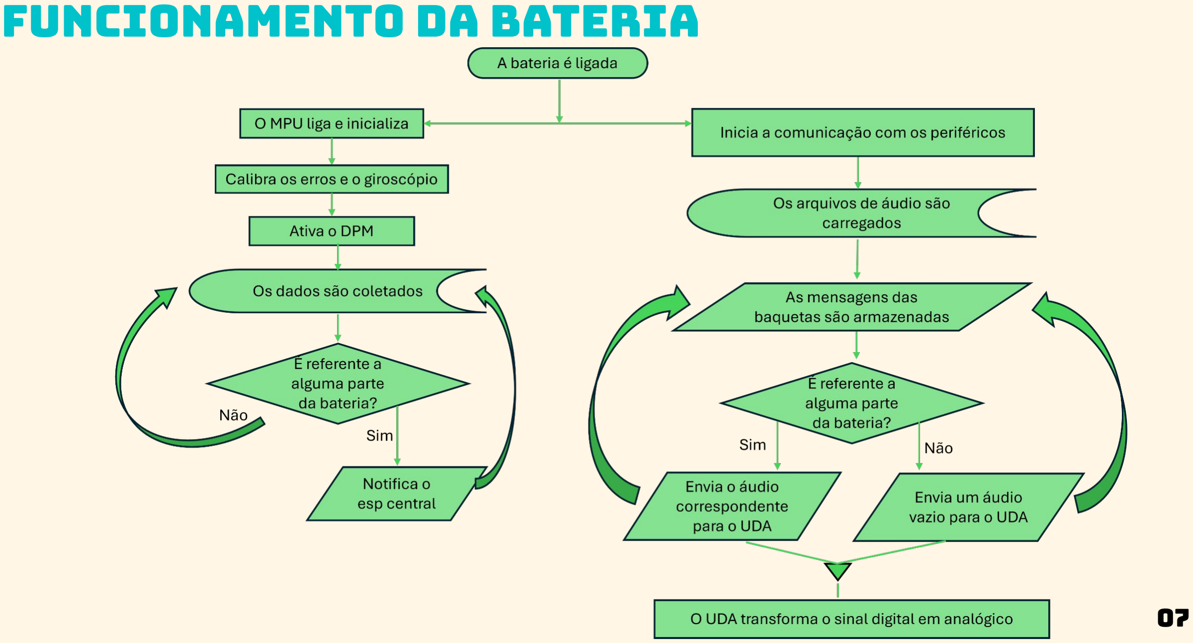
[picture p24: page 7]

# DESENVOLVIMENTO

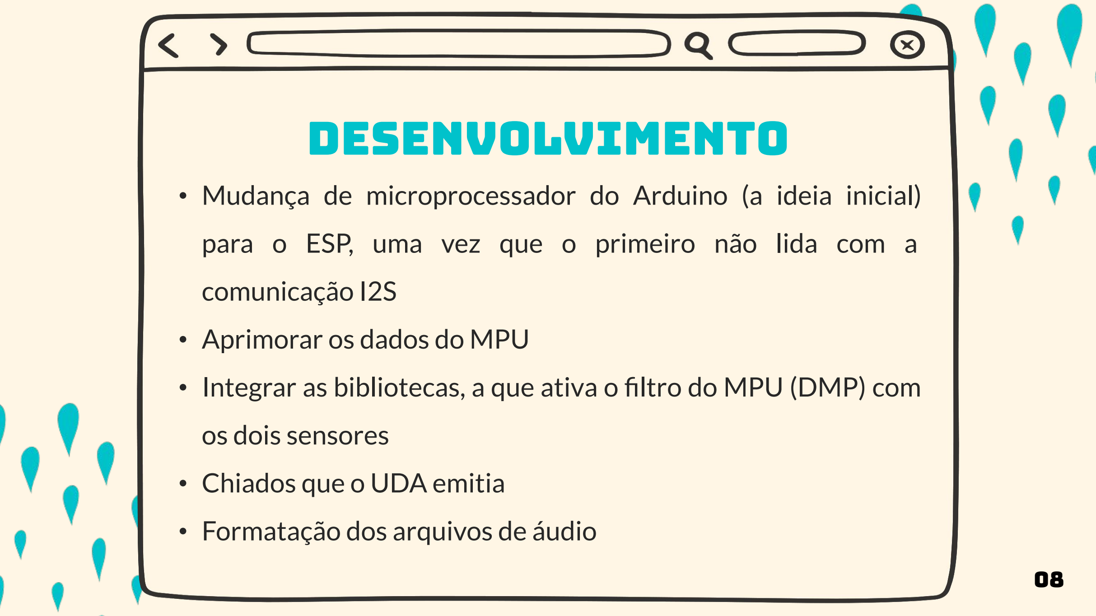
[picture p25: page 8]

- Mudança de microprocessador do Arduino (a ideia inicial)

para o ESP, uma vez que o primeiro não lida com a

comunicação I2S

- Aprimorar os dados do MPU
- Integrar as bibliotecas, a que ativa o filtro do MPU (DMP) com

os dois sensores

- Chiados que o UDA emitia
- Formatação dos arquivos de áudio

# Conclusões

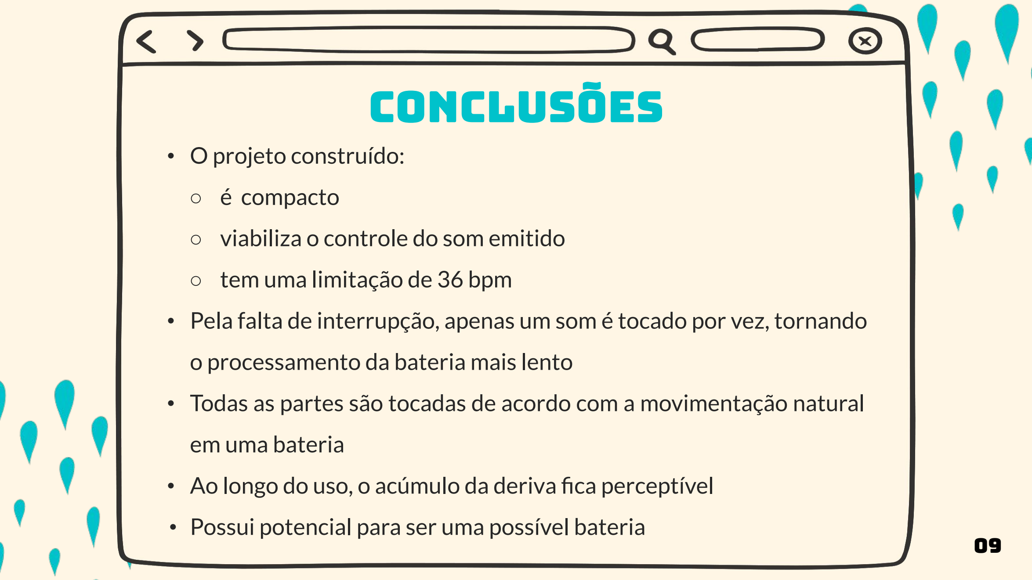
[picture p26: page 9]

- O projeto construído:
- é compacto
- viabiliza o controle do som emitido
- tem uma limitação de 36 bpm
- Pela falta de interrupção, apenas um som é tocado por vez, tornando

o processamento da bateria mais lento

- Todas as partes são tocadas de acordo com a movimentação natural

em uma bateria

- Ao longo do uso, o acúmulo da deriva fica perceptível
- Possui potencial para ser uma possível bateria

# POSSÍVEIS MELHORIAS

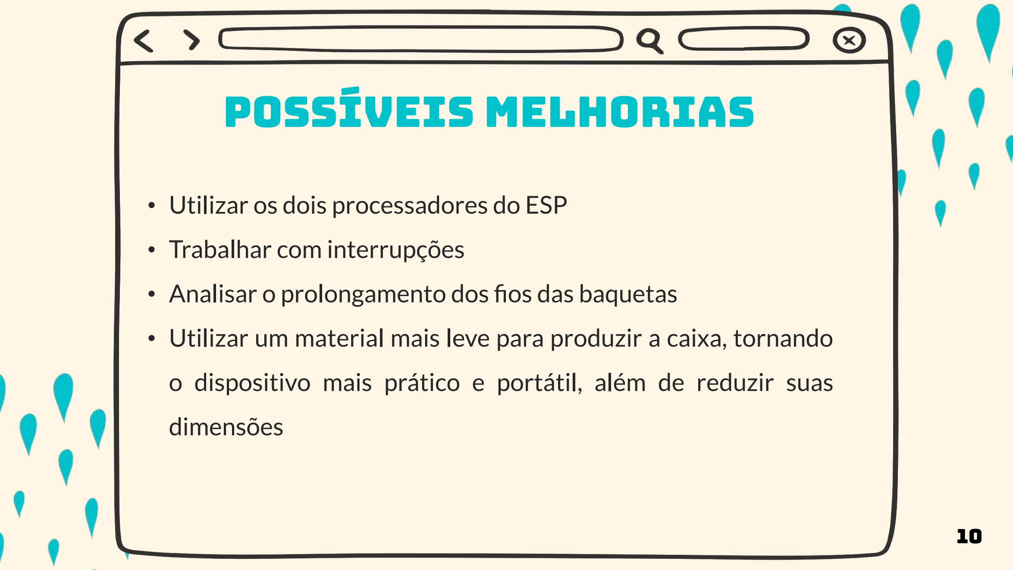
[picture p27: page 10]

- Utilizar os dois processadores do ESP
- Trabalhar com interrupções
- Analisar o prolongamento dos fios das baquetas
- Utilizar um material mais leve para produzir a caixa, tornando

o dispositivo mais prático e portátil, além de reduzir suas

dimensões

# POSSÍVEIS MELHORIAS

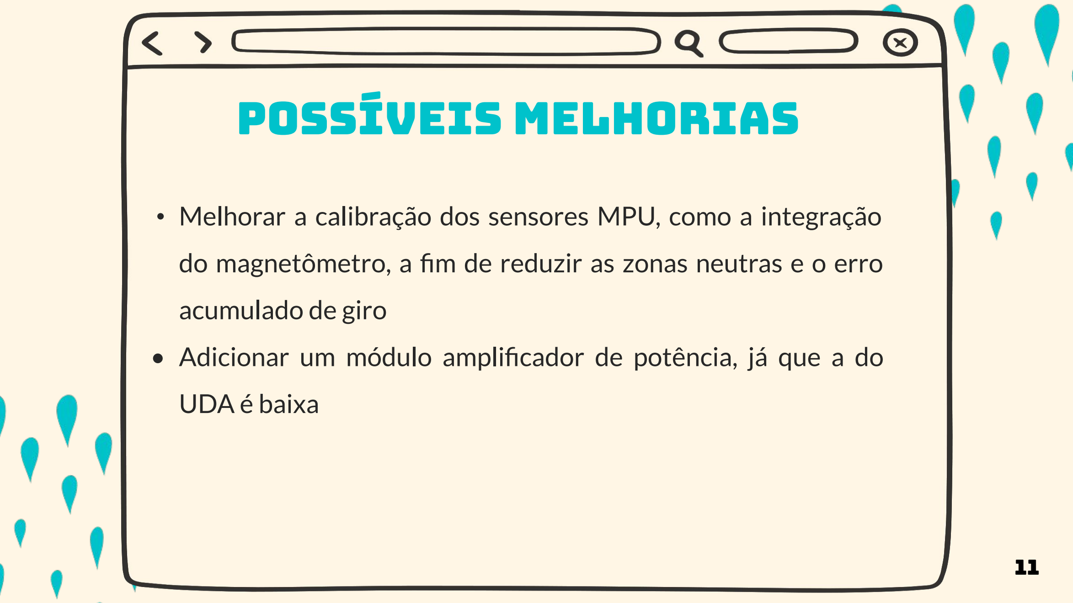
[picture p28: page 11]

- Melhorar a calibração dos sensores MPU, como a integração

do magnetômetro, a fim de reduzir as zonas neutras e o erro

acumulado de giro

- Adicionar um módulo amplificador de potência, já que a do

UDA é baixa

# Vídeo

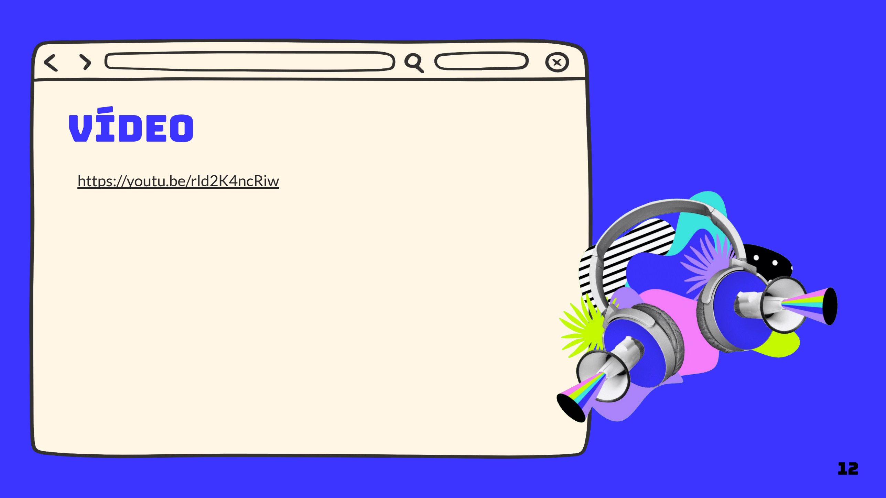
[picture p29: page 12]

https://youtu.be/rld2K4ncRiw

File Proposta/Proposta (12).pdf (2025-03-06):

Universidade Tecnologica Federal do Paran ´ | a – UTFPR ´
Departamento Academico de Inform ˆ | atica – DAINF ´
Departamento Academico de Eletr ˆ | onica – DAELN ˆ
Engenharia de Computaçaõ ELEX20 S71/S72 Oficina de Integraçao 1 ˜

# AirDrums

Bruna Medeiros Teixeira – brunat@alunos.utfpr.edu.br– (41) 992818589 Guilherme de Souza Carneiro Garcia – garciag@alunos.utfpr.edu.br – (41) 997124029 Isabela Bella Bortoleto – isabelabortoleto@alunos.utfpr.edu.br – (41) 987893146

Outubro de 2024

### 1 Introduçaõ

A ideia do projeto surgiu como uma possibilidade de simular uma bateria usando
componentes eletronicos, com o objetivo de proporcionar a sensaç ˆ | ao de tocar esse ins- ˜
trumento e facilitar o acesso ao ambiente musical. A bateria convencional e amplamente ´ utilizada na musica moderna; no entanto, ela apresenta alguns desafios para quem deseja ´ se aventurar nesse mundo:
1. Alto custo: Comparado ao salario m ´ | ínimo brasileiro de 2024, que e de R$1.412,00 ´
(1), uma bateria e consideravelmente mais cara. O preço m ´ | edio de uma bateria ´
musical convencional varia entre R$2.200 e R$3.500, dependendo da marca e dos componentes inclusos (2), o que dificulta o acesso a esse produto.
2. Barulho: Uma bateria convencional e dif ´ ícil de ser mantida em determinados tipos de moradia, uma vez que o som alto pode atrapalhar o convívio com outras pessoas.
3. Espaço: Um kit comum de bateria, composto por um bumbo, dois tons, dois pratos
e um chimbal, ocupa um espaço consideravel em um c ´ | omodo, sendo necess ˆ | ario um ´
local específico para a pratica do instrumento. ´

Tendo esses desafios em mente, o projeto busca remedia-los e aproximar as pessoas ´
da pratica musical, e tamb ´ | em da musica, uma atividade que permeia a vida urbana. ´

### 2 Descriçao do projeto ˜

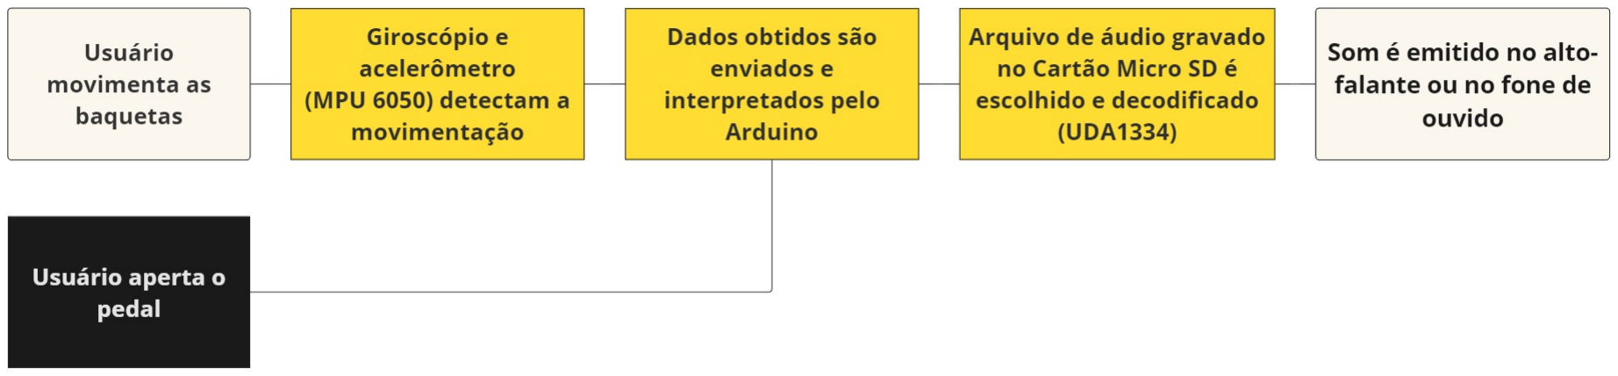
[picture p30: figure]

Figura 1: Diagrama de blocos do projeto

O projeto AirDrums consiste na detecçao de gestos feitos com baquetas, os quais ˜ simulam os movimentos de tocar uma bateria no ar, e na conversao desses movimentos ˜ em sons realistas de bateria. Para isso, o sistema utiliza sensores como acelerometros e ˆ
giroscopios (como o MPU6050) para capturar a movimentaç ´ | ao, al ˜ | em de um bot ´ | ao que ˜
simula o acionamento do bumbo.
O diagrama da figura 1 e da figura 3 mostra o fluxo dos dados desde a captura dos movimentos pelos sensores, passando pelo Arduíno, que interpreta e processa as
informaçoes, at ˜ | e a emiss ´ | ao dos sons pelo m ˜ | odulo de som. O sistema opera em um ci- ´
clo contínuo, respondendo a cada batida feita pelo usuario no ar. ´
Ao analisar cada componente, o acelerometro identifica a aceleraç ˆ | ao das m ˜ | aos nos ˜
eixos X, Y e Z, baseando-se nas mudanças bruscas de movimentaçao. Quando ocorre ˜ uma batida, ele envia esses dados ao Arduíno para que o som correspondente da bateria
seja reproduzido. O giroscopio, por sua vez, mede a rotaç ´ | ao das m ˜ | aos nos eixos X, Y e Z, ˜
detectando a orientaçao e os movimentos angulares das baquetas. Ele ajuda a identificar ˜
a direçao e o tipo de movimento, permitindo diferenciar gestos espec ˜ | íficos, como toques
no tons ou pratos, alem de melhorar a precis ´ | ao na detecç ˜ | ao das batidas. ˜
O pedal, conectado ao Arduíno, detecta quando o usuario o pressiona, acionando o ´ som do bumbo e simulando o funcionamento de um pedal de bateria tradicional. Por fim, o modulo de som reproduz os sons correspondentes a cada parte da bateria, que podem ´
estar armazenados em um cartao micro SD. O sistema tamb ˜ | em pode ser conectado a alto- ´
falantes ou fones de ouvido.
O modelo de bateria utilizado como inspiraçao para o nosso projeto ˜ | e o do baterista ´
ingles Ringo Starr, integrante da banda ˆ | The Beatles, utilizado entre os anos de 1963 e
1964, conforme ilustrado na figura 2.

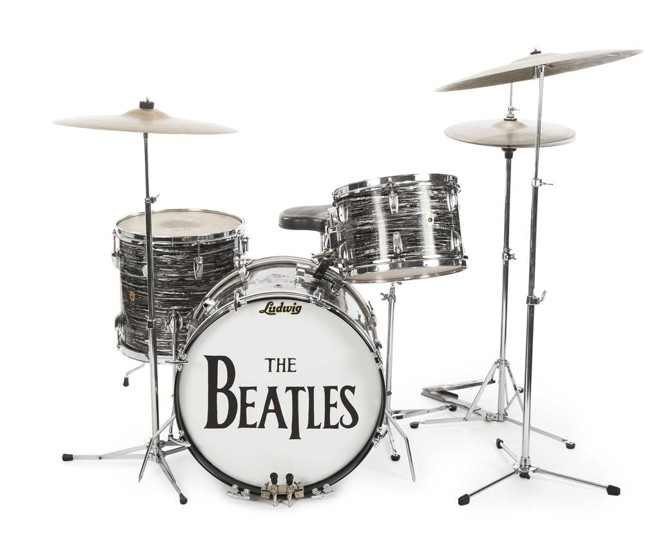
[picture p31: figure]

Figura 2: Bateria de Ringo Starr, Foto: Juliens Auctions via Reuters

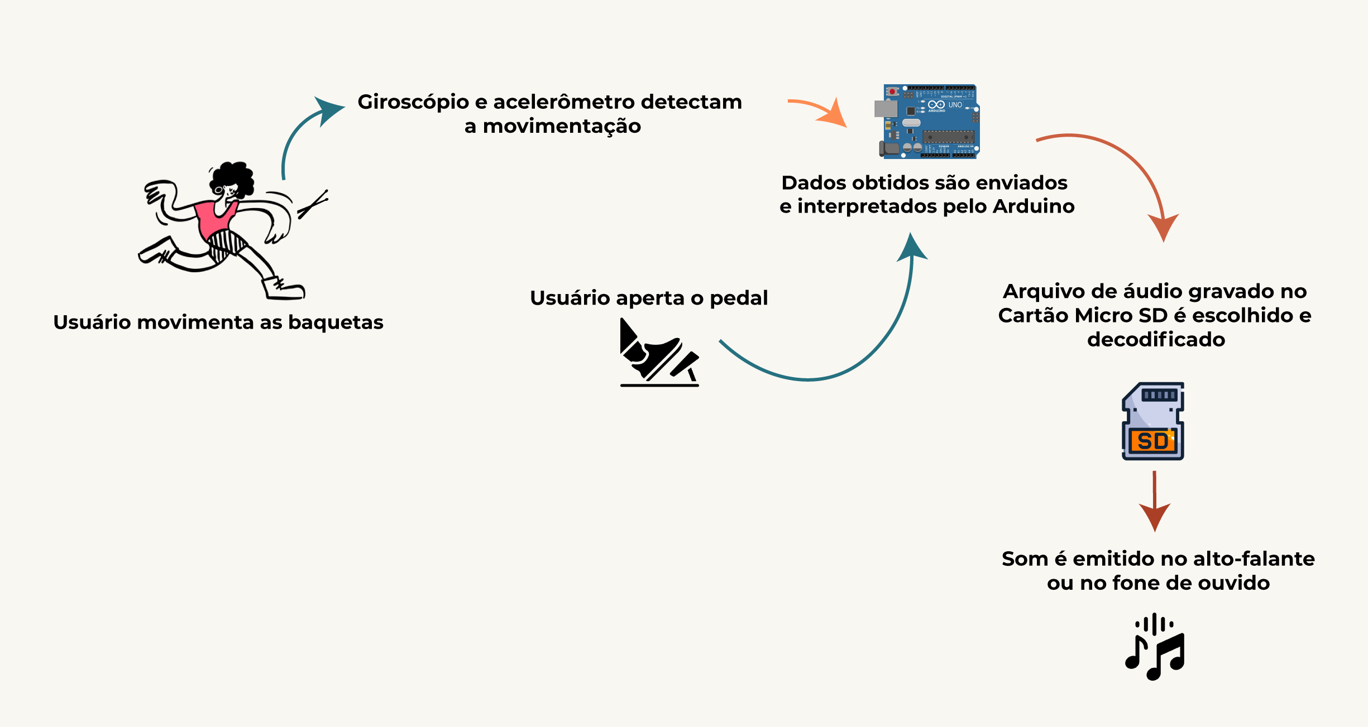
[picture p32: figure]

Figura 3: Diagrama ilustrativo do projeto

### 3 Ferramentas

### 3.1 Hardware

- Arduíno UNO (processamento dos dados das baquetas e saída do audio) ´
- 2 baquetas com sensores de giroscopio e aceler ´ | ometro (BMI160 ou MPU6050) ˆ
- Modulo de cart ´ | ao Micro SD, com o cart ˜ | ao Micro SD. ˜
- Modulo amplificador (como o PAM8403). ´
- Decodificador De Audio I2s Uda1334a. ´
- Alto-falante
- Placa PCB universal.
- Fios de conexaõ
- Push Button.
- Ferro de solda

### 3.2 Software

- Arduino IDE
- Computador
- Audacity

### 4 Cronograma

O desenvolvimento do projeto esta dividido em 3 marcos: o primeiro referente a testar ´ os componentes e integrar o seu funcionamento, o segundo tem o foco de fazer a logica ´
do funcionamento por meio de codigo e o ´ | ultimo utiliza a sa ´ | ída de som para concluir o
funcionamento, como mostra a figura 4 e 5.


Figura 4: Parte 1 do diagrama de Gantt do cronograma do projeto


Figura 5: Parte 2 do diagrama de Gantt do cronograma do projeto

Referencias Bibliogr ˆ | aficas ´
1 Ministerio do Planejamento e Orçamento. ´ | Salario m ´ | ínimo de 2024 terá
ganho real e crescera 3,85% al ´ | em dos 3,85% da inflaç ´ | aõ . 2023. Disponível
em: ⟨https://www.gov.br/planalto/pt-br/acompanhe-o-planalto/noticias/2023/12/salario-minimo-de-2024-tera-ganho-real-e-crescera-3pp-alem-dos-3-85-da-inflacao⟩.
2 Mercado Livre. Bateria acustica convencional - preços ´ | | . 2023. Acesso em: 19
out. 2024. Disponível em: ⟨https://lista.mercadolivre.com.br/bateria-musical\#D[A: bateria\%20musical]⟩.

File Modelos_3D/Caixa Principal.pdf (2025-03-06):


Produto educacional do SOLIDWORKS. Somente para fins de instrução.

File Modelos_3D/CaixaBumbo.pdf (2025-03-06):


Produto educacional do SOLIDWORKS. Somente para fins de instrução.

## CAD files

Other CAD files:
Modelos_3D/Montagem caixa.dwg

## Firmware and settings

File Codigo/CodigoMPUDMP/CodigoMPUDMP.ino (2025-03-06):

#include "I2Cdev.h"
#include "MPU6050_6Axis_MotionApps20.h"

// Definição do MPU6050 no endereço padrão
MPU6050 mpu;

// Definição de pinos no ESP32
#define SDA_PIN 21 // SDA conectado ao pino D21
#define SCL_PIN 22 // SCL conectado ao pino D22
#define INTERRUPT_PIN 4 // Pino de interrupção configurado como D4

/* Variáveis de controle */
volatile bool MPUInterrupt = false;  // Indica se ocorreu interrupção
bool DMPReady = false;               // Indica se o DMP está pronto
uint8_t devStatus;                   // Status da inicialização do DMP
uint16_t packetSize;                 // Tamanho do pacote esperado no FIFO
uint8_t FIFOBuffer[64];              // Buffer do FIFO do MPU6050
unsigned long lastHitTime = 0; // Armazena o tempo da última batida
const unsigned long hitDelay = 250; // Tempo mínimo entre as batidas (em ms)
bool tocou=false;

/* Variáveis de orientação */
Quaternion q;        // Quaternion [w, x, y, z]
VectorFloat gravity; // Vetor de gravidade [x, y, z]
float ypr[3];        // Yaw, Pitch, Roll em radianos

/* Rotina de interrupção */
void IRAM_ATTR DMPDataReady() {
  MPUInterrupt = true;
}

void setup() {
  // Inicialização da comunicação serial
  Serial.begin(115200);
  while (!Serial); // Aguarda conexão serial

  // Inicialização do I2C no ESP32
  Wire.begin(SDA_PIN, SCL_PIN);
  Wire.setClock(400000); // Velocidade do barramento I2C

  // Inicialização do MPU6050
  Serial.println("Inicializando MPU6050...");
  mpu.initialize();
  pinMode(INTERRUPT_PIN, INPUT_PULLUP); // Configuração do pino de interrupção

  // Verificar conexão com o MPU6050
  if (!mpu.testConnection()) {
    Serial.println("Erro: Conexão com o MPU6050 falhou!");
    while (1);
  }
  Serial.println("Conexão com MPU6050 bem-sucedida.");

  // Inicialização do DMP
  Serial.println("Inicializando DMP...");
  devStatus = mpu.dmpInitialize();

  // Configurar offsets (ajustar conforme necessário para sua unidade)
  mpu.setXAccelOffset(-1886);
  mpu.setYAccelOffset(-1146);
  mpu.setZAccelOffset(520);
  mpu.setXGyroOffset(82);
  mpu.setYGyroOffset(-1);
  mpu.setZGyroOffset(0);

  // Verificar se a inicialização do DMP foi bem-sucedida
  if (devStatus == 0) {
    Serial.println("DMP inicializado com sucesso. Calibrando...");

    // Calibrar acelerômetro e giroscópio
    mpu.CalibrateAccel(10);
    mpu.CalibrateGyro(10);
    Serial.println("Calibração concluída. Ativando DMP...");

    // Ativar o DMP
    mpu.setDMPEnabled(true);

    // Habilitar a detecção de interrupções
    attachInterrupt(digitalPinToInterrupt(INTERRUPT_PIN), DMPDataReady, RISING);
    DMPReady = true;

    // Obter o tamanho esperado do pacote do DMP
    packetSize = mpu.dmpGetFIFOPacketSize();
    Serial.println("DMP pronto. Aguardando dados...");
  } else {
    // Caso de falha na inicialização do DMP
    Serial.print("Erro: Falha ao inicializar DMP (código ");
    Serial.print(devStatus);
    Serial.println(")");
    while (1);
  }
  
  Serial2.begin(115200, SERIAL_8N1, -1, 17);
}

void loop() {
  if (!DMPReady) return;

  if (MPUInterrupt) {
    MPUInterrupt = false;
    //Serial2.print("Comunicando com 1");
    float yaw, pitch, roll;
    getYawPitchRoll(yaw, pitch, roll);

    //Serial.print("DIR:");  
    //Serial.print(yaw);
    //Serial.print(",");
    //Serial.print(pitch);
    //Serial.print(",");
    //Serial.println(roll);

    printYawPitchRoll(yaw, pitch, roll);
    if(tocou==false){
      tocou=tocar(yaw,pitch,roll);
      /*Serial.print("Tocou eh ");
      Serial.println(tocou);*/
    }
    else{
      //Serial.println("Tocou eh verdadeiro");
    }
    if(foraAreaBatida(roll)){
      tocou=false;
      //Serial.println("Tocou eh false, ForaAreaBatida eh true");
    }

  }
  //delay(500);
}

void getYawPitchRoll(float &yaw, float &pitch, float &roll) {
  // Lê os valores de yaw, pitch e roll
  if (mpu.dmpGetCurrentFIFOPacket(FIFOBuffer)) {
    mpu.dmpGetQuaternion(&q, FIFOBuffer);
    mpu.dmpGetGravity(&gravity, &q);
    mpu.dmpGetYawPitchRoll(ypr, &q, &gravity);

    // Converter para graus
    yaw = ypr[0] * 180 / M_PI;
    pitch = ypr[1] * 180 / M_PI;
    roll = ypr[2] * 180 / M_PI;
  }
}

bool tocar(float yaw, float pitch, float roll) {
  unsigned long currentTime = millis(); // Tempo atual

  // Verifica o "Tom direito"
  if (yaw > 15 && yaw < 45 && roll < -10 && (currentTime - lastHitTime > hitDelay)) {// antes a condição do roll era -40 e o yaw era 20 e 45
    Serial.println("Batida detectada");
    Serial2.print("Tom direito");
    printYawPitchRoll(yaw, pitch, roll);
    lastHitTime = currentTime; // Atualiza o tempo da última batida
    return true;
  }

  // Verifica o "Prato direito"
  else if (yaw > 60 && roll < -10 && (currentTime - lastHitTime > hitDelay)) {//antes a condição do roll era -40 e yaw era 70
    Serial.println("Batida detectada");
    Serial2.print("Prato direito");
    printYawPitchRoll(yaw, pitch, roll);
    lastHitTime = currentTime;
    return true;
  }

  // Verifica o "Tom esquerdo"
  else if (yaw > -45 && yaw < -15 && roll < -10 && (currentTime - lastHitTime > hitDelay)) {//antes a condição do roll era -40 e yaw era -50 e -20
    Serial.println("Batida detectada");
    Serial2.print("Tom esquerdo");
    printYawPitchRoll(yaw, pitch, roll);
    lastHitTime = currentTime;
    return true;
  }

  // Verifica o "Prato esquerdo"
  else if (yaw < -60 && roll < -10 && (currentTime - lastHitTime > hitDelay)) {//antes a condição do roll era -40 e yaw era -70
    Serial.println("Batida detectada");
    Serial2.print("Prato esquerdo");
    printYawPitchRoll(yaw, pitch, roll);
    lastHitTime = currentTime;
    return true;
  }
  else{
    return false;
    Serial.println("Tocou esta retornando falso");
  }
  // Exemplo: Adicione mais condições se necessário
}

void printYawPitchRoll(float yaw, float pitch, float roll) {
  Serial.print("Yaw: ");
  Serial.print(yaw);
  Serial.print(", Pitch: ");
  Serial.print(pitch);
  Serial.print(", Roll: ");
  Serial.println(roll);
}

bool foraAreaBatida(float roll) {
  if (roll >5) {
    //Serial.println("Fora da area de batida!");
    return true; // Retorna verdadeiro se uma batida for detectada
  }
  return false; // Retorna falso caso contrário
}

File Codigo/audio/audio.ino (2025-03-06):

#include "Arduino.h"
#include "SD.h"
#include "FS.h"
#include "driver/i2s.h"

// Pin definitions
#define SD_CS          5
#define SPI_MOSI      23
#define SPI_MISO      19
#define SPI_SCK       18
#define I2S_BCLK      14
#define I2S_LRC       15
#define I2S_DOUT      22
#define BUMBO 4 // Porta do Bumbo
// Buffer size
#define AUDIO_BUFFER_SIZE 512

File audioFile;
unsigned long lastHitTime = 0;       // Armazena o tempo da última batida
const unsigned long hitDelay = 250;  // Tempo mínimo entre as batidas (em ms)
bool tocou = false;

void setupI2S() {
    // ConfiguraÃ§Ã£o do driver I2S
    i2s_config_t i2s_config = {
        .mode = (i2s_mode_t)(I2S_MODE_MASTER | I2S_MODE_TX), // Modo Master e transmissÃ£o
        .sample_rate = 44100,                               // Taxa de amostragem: 44.1 kHz
        .bits_per_sample = I2S_BITS_PER_SAMPLE_16BIT,       // 16 bits por amostra
        .channel_format = I2S_CHANNEL_FMT_RIGHT_LEFT,       // Formato estÃ©reo
        .communication_format = I2S_COMM_FORMAT_I2S,        // ComunicaÃ§Ã£o I2S padrÃ£o
        .intr_alloc_flags = ESP_INTR_FLAG_LEVEL1,           // InterrupÃ§Ã£o
        .dma_buf_count = 8,                                 // NÃºmero de buffers DMA
        .dma_buf_len = 64                                   // Tamanho de cada buffer
    };

    // Inicializa o driver I2S
    i2s_driver_install(I2S_NUM_0, &i2s_config, 0, NULL);

    // ConfiguraÃ§Ã£o dos pinos I2S
    i2s_pin_config_t pin_config = {
        .bck_io_num = I2S_BCLK,     // Pino do BCLK
        .ws_io_num = I2S_LRC,       // Pino do LRC
        .data_out_num = I2S_DOUT,   // Pino do DOUT
        .data_in_num = I2S_PIN_NO_CHANGE // Sem pino de entrada
    };

    i2s_set_pin(I2S_NUM_0, &pin_config);

    // Configura o clock I2S
    i2s_set_clk(I2S_NUM_0, 44100, I2S_BITS_PER_SAMPLE_16BIT, I2S_CHANNEL_STEREO);
}

void setup() {
    // Inicializa o monitor serial
    Serial.begin(115200);

    // Inicializa o cartÃ£o SD
    pinMode(SD_CS, OUTPUT);
    digitalWrite(SD_CS, HIGH);
    SPI.begin(SPI_SCK, SPI_MISO, SPI_MOSI);

    if (!SD.begin(SD_CS)) {
        Serial.println("Falha ao inicializar o cartÃ£o SD!");
        while (1);
    }
    Serial.println("CartÃ£o SD inicializado!");

    // Configura o I2S
    setupI2S();

    // Abre o arquivo de Ã¡udio no SD
    audioFile = SD.open("/teste.wav", FILE_READ);
    if (!audioFile) {
        Serial.println("Falha ao abrir o arquivo de Ã¡udio!");
        while (1);
    }
    Serial.println("Arquivo de Ã¡udio carregado!");
    pinMode(BUMBO, INPUT_PULLDOWN);
}

void loop() {
 handleButtonPress();
}

void handleButtonPress() {
  // Read the state of the button
  int pinState = digitalRead(BUMBO);

  // Play the audio if the button is pressed
  if (pinState == LOW) { // Assuming LOW means pressed
    unsigned long currentTime = millis();

    // Ensure a delay between consecutive plays
    if (currentTime - lastHitTime > hitDelay) {
      Serial.println("BUMBO detected via button press");
      playAudio("/Bumbo.wav");
      lastHitTime = currentTime;
    }
  }
}
void playAudio(const char *fileName) {
  // Open the file from SD card
  audioFile = SD.open(fileName, FILE_READ);
  if (!audioFile) {
    Serial.println("Erro ao abrir o arquivo de áudio!");
    return;
  }

  Serial.println("Reproduzindo áudio...");

   if (audioFile.available()) {
        // Cria um buffer para armazenar os dados do arquivo
        uint8_t audioBuffer[AUDIO_BUFFER_SIZE];
        int bytesRead = audioFile.read(audioBuffer, AUDIO_BUFFER_SIZE);

        // Envia os dados para o I2S
        size_t bytesWritten;
        i2s_write(I2S_NUM_0, audioBuffer, bytesRead, &bytesWritten, portMAX_DELAY);
    } 
  Serial.println("Áudio finalizado.");
}
